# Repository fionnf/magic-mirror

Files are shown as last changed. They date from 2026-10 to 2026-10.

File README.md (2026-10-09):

# House Fortuna wall

A 192 × 192 pixel LED art wall for a living room: nine 64 × 64 HUB75 panels driven by a
Raspberry Pi 4, controlled from a phone web app. It shows slow generative art, GPU shaders and
video loops, responds (subtly) to the music in the room, and can also act as a camera mirror
with AI one-liners and a receipt printer.

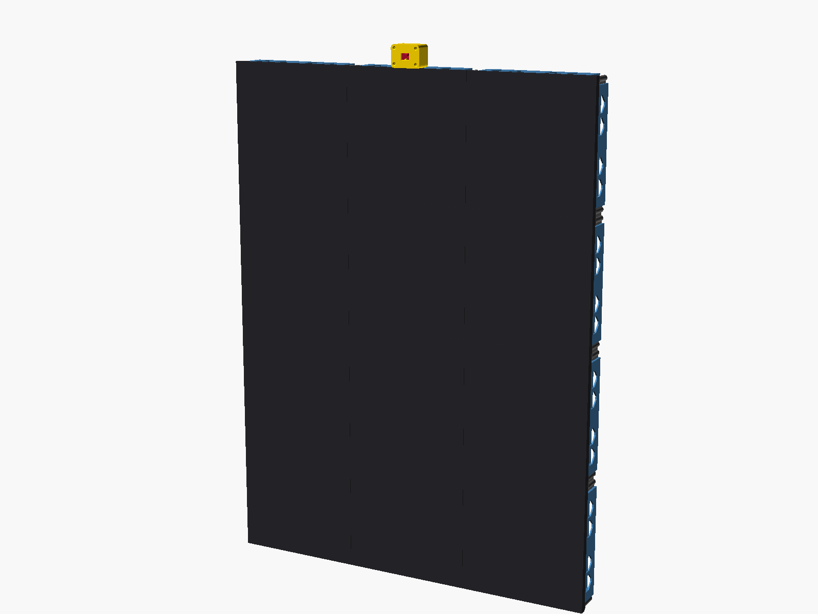
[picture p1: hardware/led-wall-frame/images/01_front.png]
front


## What it does

| Mode | What you see |
|---|---|
| **Art** (Artsy, Shaders, Shapes, Light Art, Lava & Coral) | Slow galleries that cross-fade; pace set in the app ("Art pace") |
| **Music** | Art that follows the room's sound. The party slider goes from "art just breathes" to dance floor; pieces, video loops and shaders are curated per level; a beat tracker, Shazam song names, an optional Claude designer |
| **Mirror** | Camera silhouette, countdown photo, a Claude one-liner, aura reading, pixel selfie, printed receipt; people recognition is opt-in |
| **Shows & live** | Welcome / Pride / story animations, VBZ-style tram board for Rennweg |
| **Extras** | Smart Life lights (living-room group), guest dedications via QR, a tour that rotates through everything |

## Hardware

| Part | Notes |
|---|---|
| Raspberry Pi 4 | Pi 5 is not supported by the panel library |
| Adafruit RGB Matrix HAT | `hardware_mapping = "regular"` (not `adafruit-hat`) |
| 9 × 64 × 64 HUB75 panels (P4, 256 mm) | 3 × 3, one chain, FM6126A driver, row serpentine from the bottom left (see `config.py`) |
| 5 V / 40 A PSU | Software current limiter at 28 A |
| Camera Module 3 | Mirror mode |
| Logitech C270 (its microphone) | Music mode's mic (any USB mic works) |
| 58 mm ESC/POS USB printer *(optional)* | Receipts |

The printable frame (3D models, OpenSCAD sources, print list) is in
[`hardware/led-wall-frame`](hardware/led-wall-frame/README.md).

## Quick start

**On a laptop (no hardware):**
```bash
python3 -m venv .venv && .venv/bin/pip install -r requirements-dev.txt
./panel_setup/sim.sh            # http://localhost:8080 - panels open in a window
```

**On a fresh Pi** (Raspberry Pi OS Lite 64-bit):
```bash
# laptop:
PI_USER=pi PI_HOST=<pi-ip> ./panel_setup/deploy.sh
scp .env pi@<pi-ip>:~/magic-mirror/.env
# pi:
cd ~/magic-mirror && ./panel_setup/bootstrap_pi.sh && sudo reboot
```
Then open `http://<pi-ip>/` on your phone. Details, tuning and troubleshooting:
[`panel_setup/README.md`](panel_setup/README.md).

## Configuration

`.env` (git-ignored; copy from `.env.example`):

| Variable | For |
|---|---|
| `ANTHROPIC_API_KEY` | All AI features (mirror lines, aura, booth prompts, wheel, music designer) - model `config.AI_MODEL` |
| `GOOGLE_DRIVE_FOLDER_ID`, `GOOGLE_DRIVE_RECEIPTS_FOLDER_ID` | Optional photo archive (`tools/auth_drive.py` once) |

Panel layout, timing, brightness and the power budget live in `config.py`.
App settings (party level, art pace, palette, people, lights…) are stored as JSON under
`panel_setup/` on the Pi and never deployed over.

## Layout

```
config.py, led_matrix.py      panel layout + driver (remapping, power limiter)
main.py, api.py               mirror mode (state machine) and its internal API
ai_client.py                  Claude calls (vision one-liner, aura, booth prompts, JSON helper)
camera.py, vision.py, smartcrop.py, faces.py, moods.py   camera, silhouette, crop, recognition
printer.py, photo_store.py, cloud_uploader.py           receipts and photo archive
lights.py                     Smart Life (Tuya) local control
display/                      everything drawn on the wall
  art.py shapes.py light_art.py artsy.py organic.py     generative galleries
  shaders.py (+ assets/shaders/*.frag)                  GPU shaders (EGL on the Pi)
  loops.py (+ assets/loops, tools/make_loops.py)        video loops
  music.py beat.py intensity.py vj_fx.py                music engine
  departures.py welcome.py pride_show.py …              live boards and shows
panel_setup/                  wall_control.py (app server + process runner), web/ (the app),
                              play.py (runs one mode), deploy/bootstrap/sim scripts, README
simulator/                    pygame panel window, webcam/button mocks
hardware/led-wall-frame/      the printable frame
```

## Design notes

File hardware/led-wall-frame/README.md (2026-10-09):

# Modular LED Wall Frame – 3 × 4 P4 64×64 panels (256 mm)

A fully printable, support-free mounting frame for twelve P4 64×64 HUB75 LED panels
(256 × 256 mm, e.g. `P4-2121-64X64-32S`) in a 3 × 4 grid. Overall size 768.6 × 1024.9 mm,
46 mm deep, so a Raspberry Pi 4/5 with HUB75 shield and a 5 V 40 A supply hide inside.
A small pod on the top edge holds a Raspberry Pi Camera Module 3 (or a Logitech C270).

Every part prints flat, with no supports, and fits a 250 × 220 mm bed (Prusa CORE One, Bambu X1/P1/H2, Prusa MK4…).
The compact Pi holder, camera pod, touch box and test pieces also fit 180 mm beds.

front

## What's in the box

| Folder | Contents |
|---|---|
| `3mf/` | Ready-to-slice plates, one object per part (open in PrusaSlicer, Bambu Studio, OrcaSlicer) |
| `stl/` | The same plates as STL |
| `source/` | Fully parametric OpenSCAD source (`led_wall_frame.scad`, `c270_webcam_box.scad`, `touch_box.scad`) |
| `images/` | Renders |

## Print list

| File | Qty | Notes |
|---|---|---|
| `00_fit_test_PRINT_FIRST` | 1 | Junction node + rail ends: check dovetail fit, M3 screw and wall keyhole |
| `00b_dovetail_gauge_c005_c010_c015` | 1 | Optional: 3 sockets at 0.05 / 0.10 / 0.15 mm clearance (1–3 dots) |
| `01_nodes_junction_x6` | 1 | |
| `02_nodes_edge_x10_corner_x4` | 1 | |
| `03_rails_vertical_x7` | 1 | |
| `04_rails_vertical_x1_horizontal_x6` | 1 | |
| `05_rails_horizontal_x3_outer_x6` | 1 | |
| `06_rails_outer_x7_top_mount_x1` | 1 | Includes the top-centre rail the camera pod screws to |
| `07_pi_tray_*` **or** `07_pi_holder_compact_*` | 1 | Pick one: full-width tray (stronger) or compact holder (fits 180 mm beds). `selftap` / `insert` (M2.5 heat-set) / `nut` (M2.5 bolt + nut). Pi 4 and Pi 5 share the hole pattern. |
| `08_psu_tray_A-200AF-5` | 1 | For a 190 × 84 × 30 mm 5 V 40 A supply (CZCL A-200AF-5) |
| `09_camera_module3_pod` **or** `10_c270_webcam_box` | 1 | Camera Module 3 (portrait, 15° down) or Logitech C270 (snap-on lid) |
| `11_touch_box_TTP223` / `11_touch_box_25mm_pad` | optional | 40 × 40 × 10 mm "roaming" capacitive touch button, 0.6 mm skin |
| `12_OPTIONAL_wall_ears_set` | optional | Only if you prefer ear brackets over the built-in keyholes |

Roughly 2 kg of filament for the full build.

## Print settings

- PETG (panels run warm – avoid PLA)
- 0.4 mm nozzle, 0.20 mm layers
- 5 perimeters, 40 % gyroid, 5 top / 5 bottom layers
- No supports, no brim, keep elephant-foot compensation on
- Print as laid out (panel side down). Touch box: front face down, 100 % infill.

## Hardware

| Item | Qty |
|---|---|
| M3 × 20 flat-head countersunk (DIN 7991 / ISO 10642) – panel screws | 84 (+2 optional) |
| 2 mm hex key with a long shaft (≥ 35 mm reach) | 1 |
| M3 × 12 pan/cheese head – camera pod or C270 box to the top rail | 2 |
| M3 × 12 countersunk – camera pod lid | 4 |
| M2 × 5 self-tapping – Camera Module 3 | 4 |
| M2.5 × 6 (+ 4 heat-set inserts for `insert`, or M2.5 × 10 + nuts for `nut`) – Pi | 4 |
| Zip ties ≥ 300 × 4.8 mm – around the PSU | 2 |
| Wall screws, pan head ≤ 8.2 mm, standing ~5 mm proud, + anchors (keyholes on a 256.3 mm grid) | 6 |
| Touch box: M2 × 8 countersunk self-tapping | 4 |
| Wall ears only: M3 × 50 countersunk at the 8 ear-node screws, 5 mm wall screws | 8 / 12 |

Electronics: 12 × P4 64×64 HUB75 panels, Raspberry Pi 5 (or 4) + active cooler, HUB75 driver shield,
Camera Module 3 + 500 mm camera cable (Pi 5: 22→15 pin) **or** Logitech C270, CZCL A-200AF-5 5 V 40 A supply,
HUB75 ribbons, panel power leads, 1.5–2.5 mm² 5 V wiring, mains cable, fuse + switch.

## Assembly

1. Lay the panels face down on a soft mat, all "up" arrows on the back pointing the same way.
2. Place the nodes on the panel corner inserts (8 mm from each edge).
3. Drop the rails in from above – the dovetails slide down over the node tenons. Horizontal rails: engraved arrow up.
4. Screw everything down with M3 × 20 (heads sit flush deep inside the posts).
5. Press the PSU tray and Pi tray into the rail windows: shift ~5 mm sideways, push one end's plugs in, bring the other end in, slide back to centre.
6. Fit the camera pod (or C270 box) on the top-centre rail; route the cable down through the rail window.
7. Hang the frame on six wall screws.

The two outer top rails have a mid screw hole at the top-centre of the outer panels – only use it if your panels have an insert there.

## Customising

All key values are at the top of `source/led_wall_frame.scad`:
`H` (frame depth), `screw_L` (panel screw length), `c` (dovetail clearance), `plug_cl` / `crush` (holder fit),
`pi_stack` (Pi + shield height), `psu_L` / `psu_Wd` (power supply size).

```
openscad -D 'part="plate_rails_A"' -o rails.stl source/led_wall_frame.scad
```

## Notes

- A single 200 W supply is short for 12 panels at full white (~240 W): cap the brightness (e.g. `--led-brightness`) or add a second supply.
- Mains: cover the AC terminals, strain-relieve the cable, fuse and switch outside the frame.
- Default Pi + shield stack: ≤ 32 mm above the Pi board.

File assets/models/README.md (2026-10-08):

# Models

`face_detection_yunet_2023mar.onnx` - YuNet face detector (~230 KB), used by `smartcrop.py` to keep
people in frame when photos are cut to portrait. Source: OpenCV Zoo
(https://github.com/opencv/opencv_zoo/tree/main/models/face_detection_yunet), MIT licence,
copyright (c) 2020 Shiqi Yu. Runs locally; nothing is sent anywhere. Needs OpenCV >= 4.5.4.

`face_recognition_sface_2021dec_int8.onnx` - SFace face recogniser (~9.9 MB, Apache-2.0, OpenCV Zoo
`face_recognition_sface`). Not committed: fetch with `./get_models.sh`. It turns a face into 128 numbers;
`faces.py` compares them. Only those numbers (never photos) are stored, and only for people who enrol.

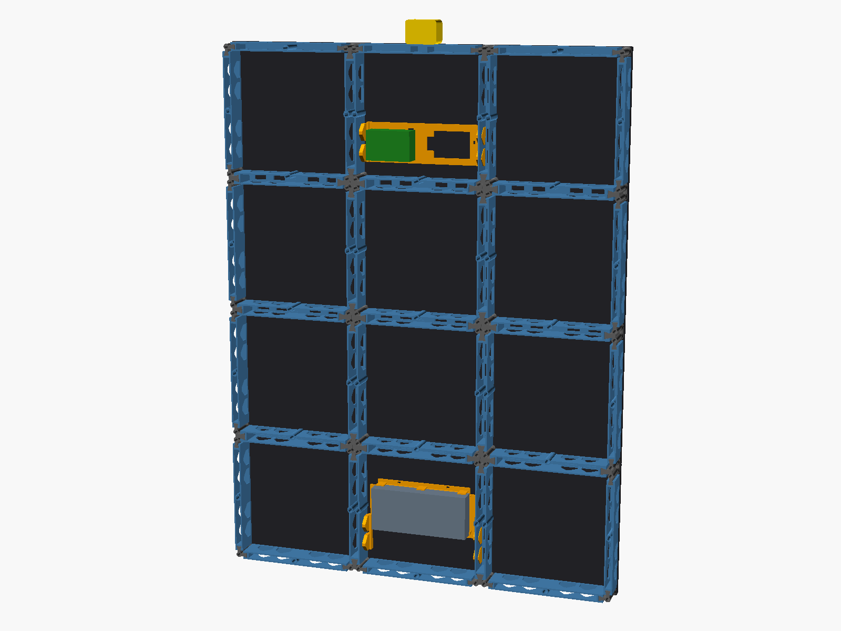
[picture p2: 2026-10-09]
hardware/led-wall-frame/images/02_rear.png

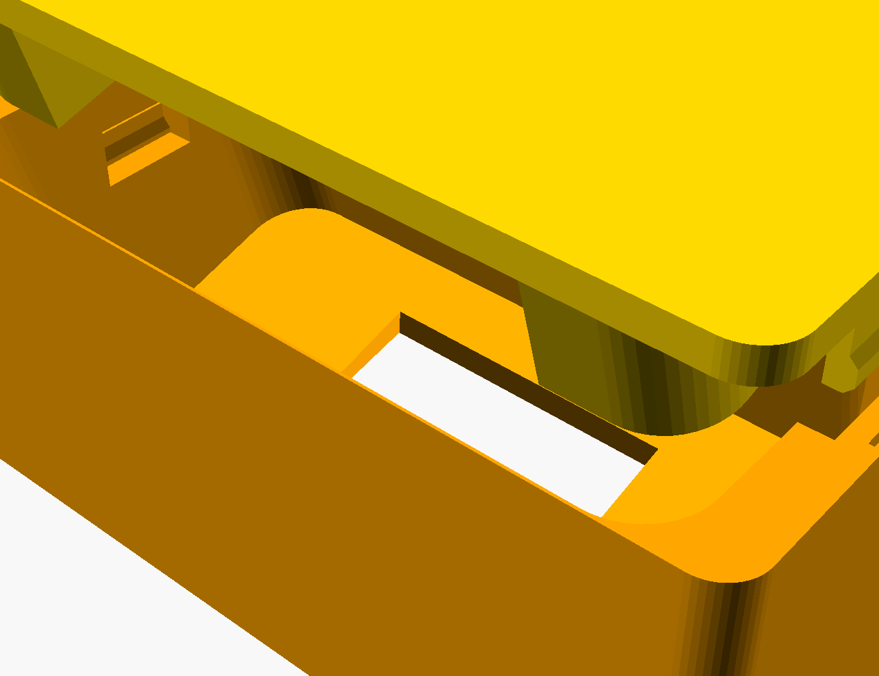
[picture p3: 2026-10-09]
hardware/led-wall-frame/images/12_c270_box_snap_lid.png

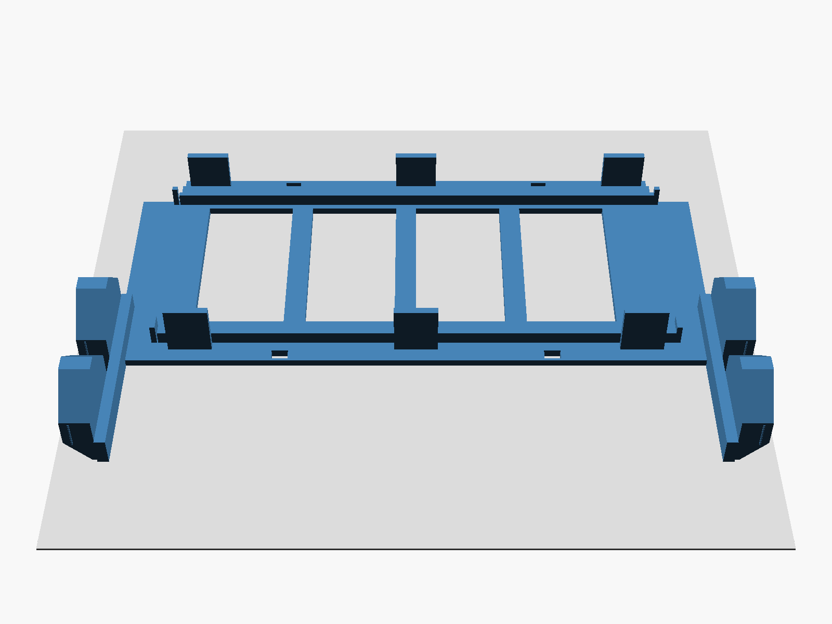
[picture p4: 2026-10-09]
hardware/led-wall-frame/images/10_plate_psu_tray.png

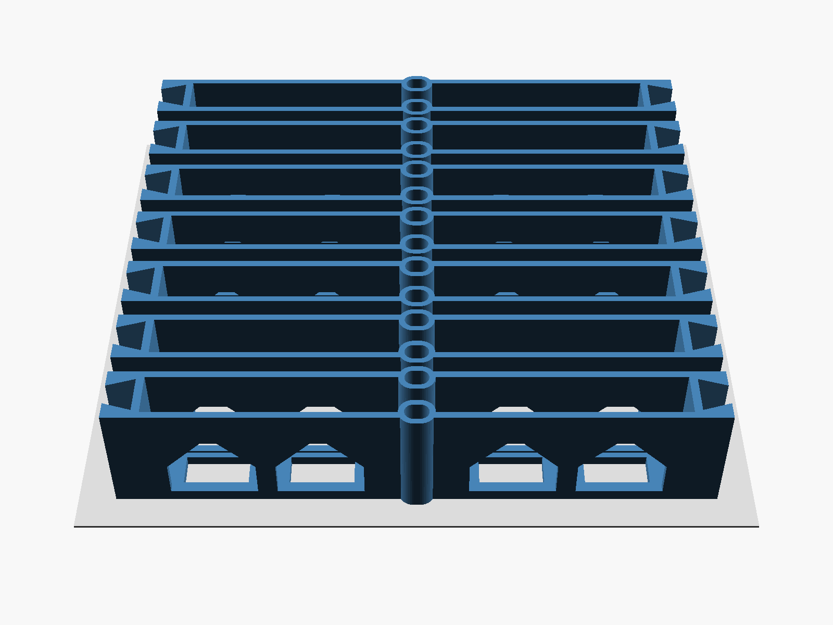
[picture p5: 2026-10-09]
hardware/led-wall-frame/images/09_plate_rails.png

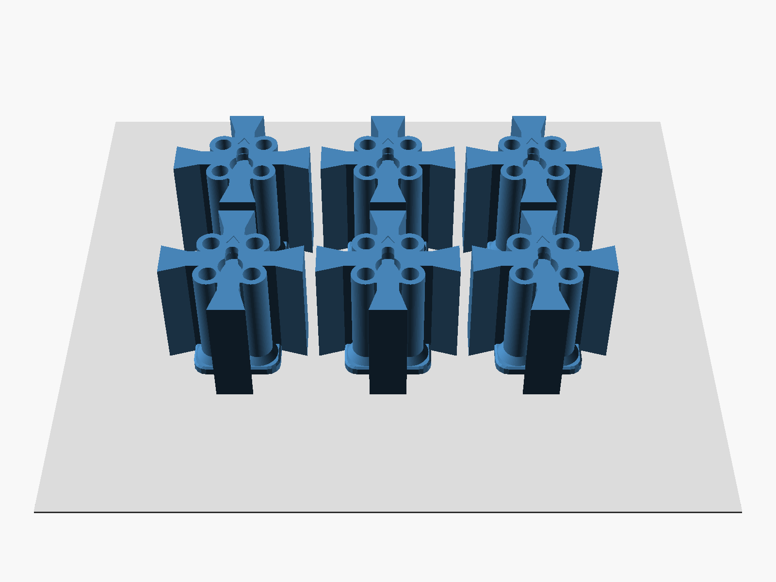
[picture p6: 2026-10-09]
hardware/led-wall-frame/images/08_plate_nodes.png

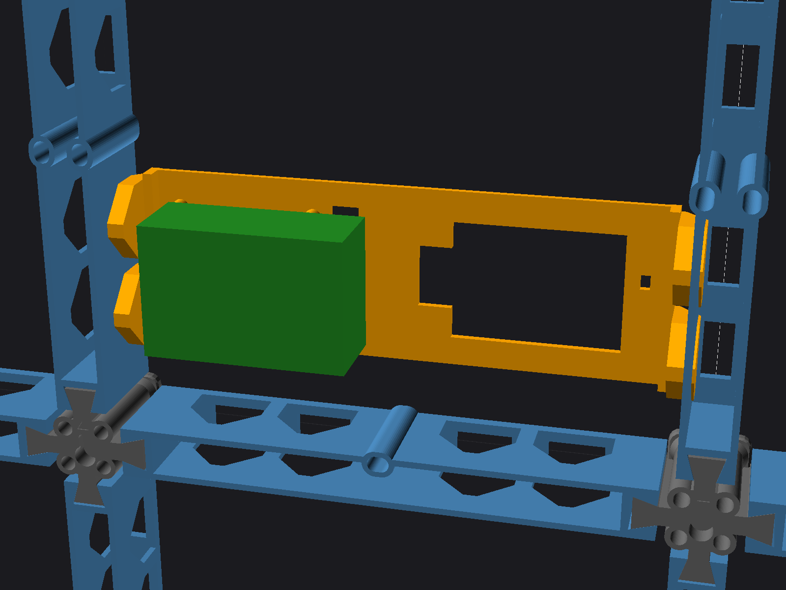
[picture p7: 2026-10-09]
hardware/led-wall-frame/images/04_pi_tray.png

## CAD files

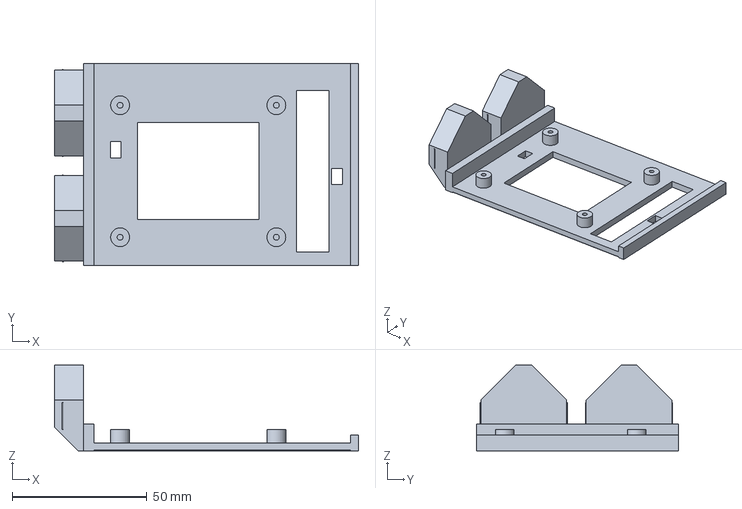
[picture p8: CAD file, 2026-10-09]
hardware/led-wall-frame/3mf/07_pi_holder_compact_selftap.3mf
112.9 x 75.0 x 31.9 mm

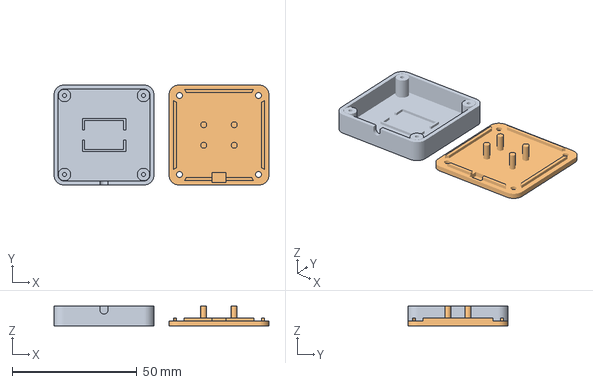
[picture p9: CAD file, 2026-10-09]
hardware/led-wall-frame/3mf/11_touch_box_TTP223.3mf
86.0 x 40.0 x 8.00 mm
touch box 1
touch box 2

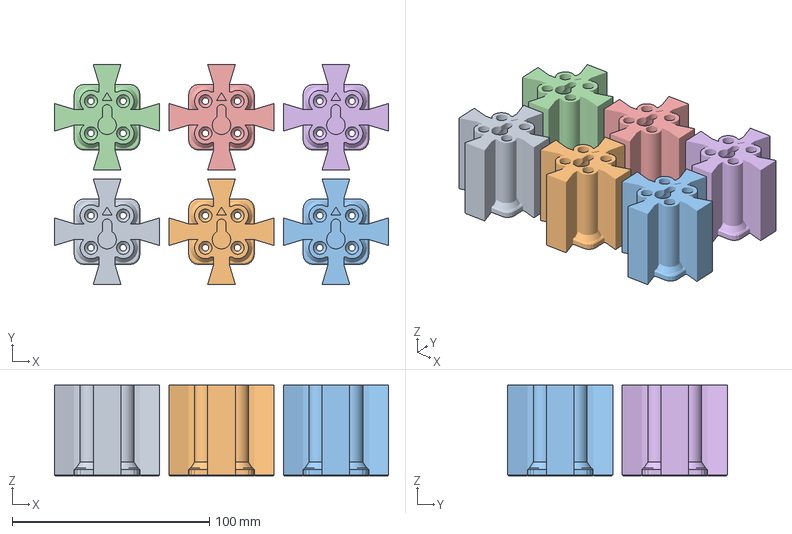
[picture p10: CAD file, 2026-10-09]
hardware/led-wall-frame/3mf/01_nodes_junction_x6.3mf
169.3 x 111.3 x 46.0 mm
junction node 1
junction node 2
junction node 3
junction node 4
junction node 5
junction node 6

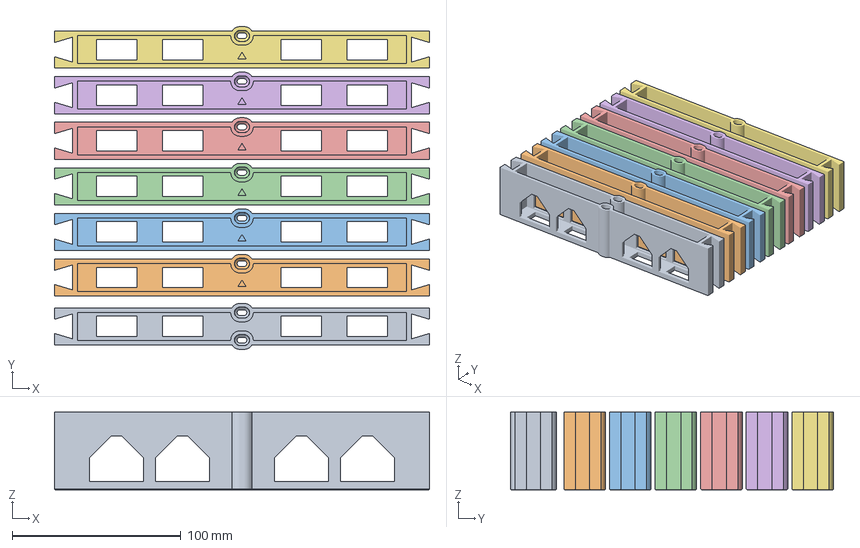
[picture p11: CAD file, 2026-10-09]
hardware/led-wall-frame/3mf/04_rails_vertical_x1_horizontal_x6.3mf
222.2 x 191.3 x 46.0 mm
rail 1
rail 2
rail 3
rail 4
rail 5
rail 6
rail 7

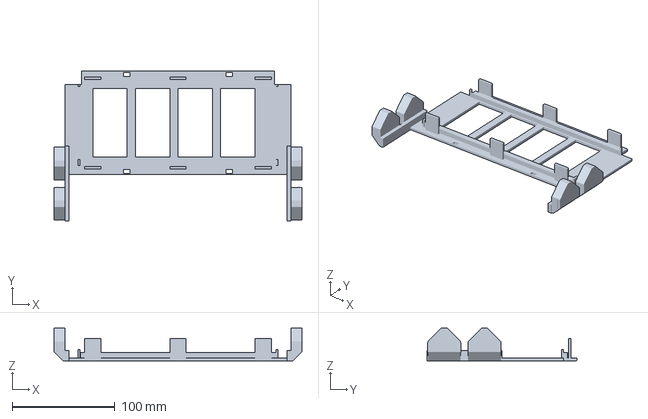
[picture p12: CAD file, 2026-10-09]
hardware/led-wall-frame/3mf/08_psu_tray_A-200AF-5.3mf
241.7 x 146.1 x 31.9 mm

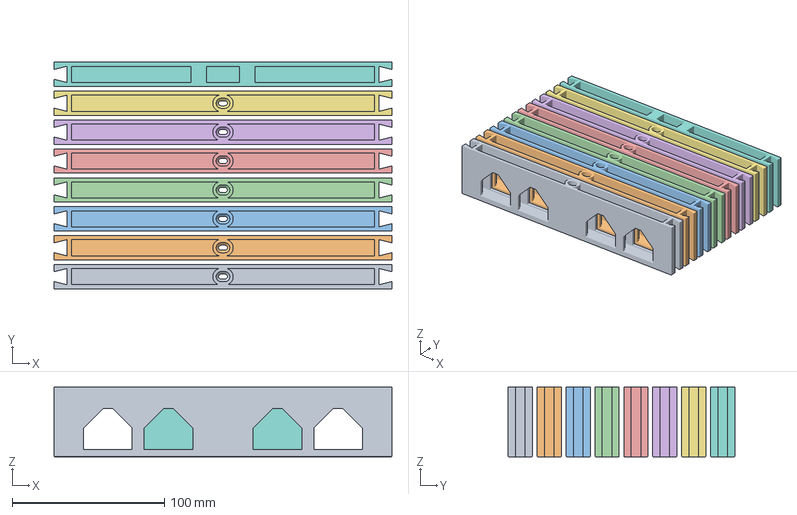
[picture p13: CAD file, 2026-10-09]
hardware/led-wall-frame/3mf/06_rails_outer_x7_top_mount_x1.3mf
222.2 x 149.0 x 46.0 mm
rail 1
rail 2
rail 3
rail 4
rail 5
rail 6
rail 7
rail 8

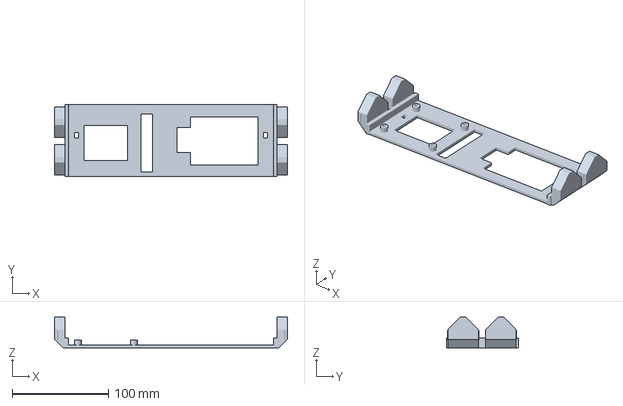
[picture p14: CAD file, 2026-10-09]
hardware/led-wall-frame/3mf/07_pi_tray_insert.3mf
241.7 x 75.0 x 31.9 mm

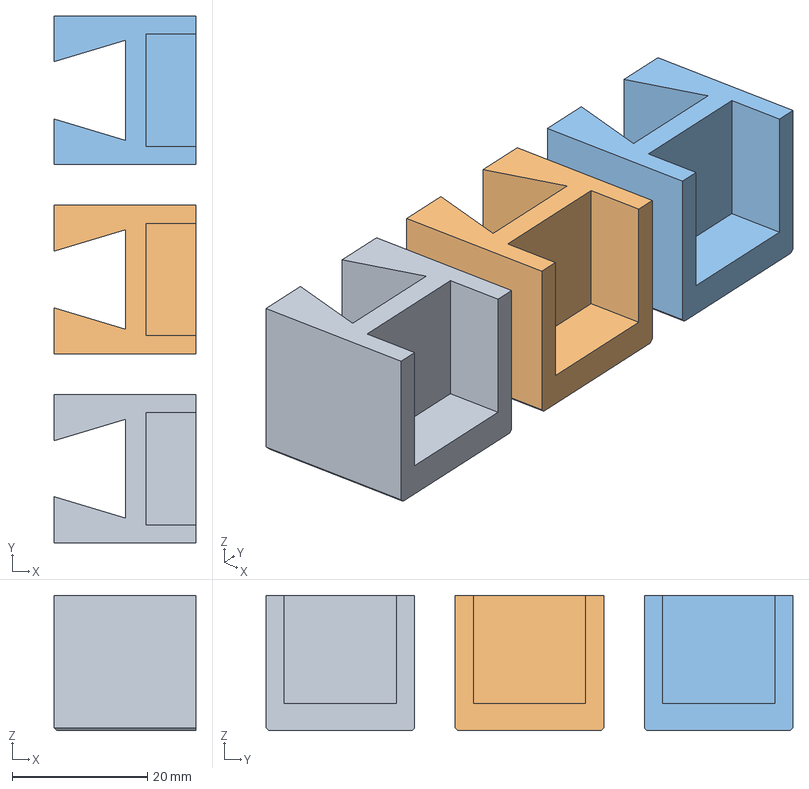
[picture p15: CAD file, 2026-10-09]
hardware/led-wall-frame/3mf/00b_dovetail_gauge_c005_c010_c015.3mf
21.0 x 78.0 x 20.0 mm
dovetail gauge 1
dovetail gauge 2
dovetail gauge 3

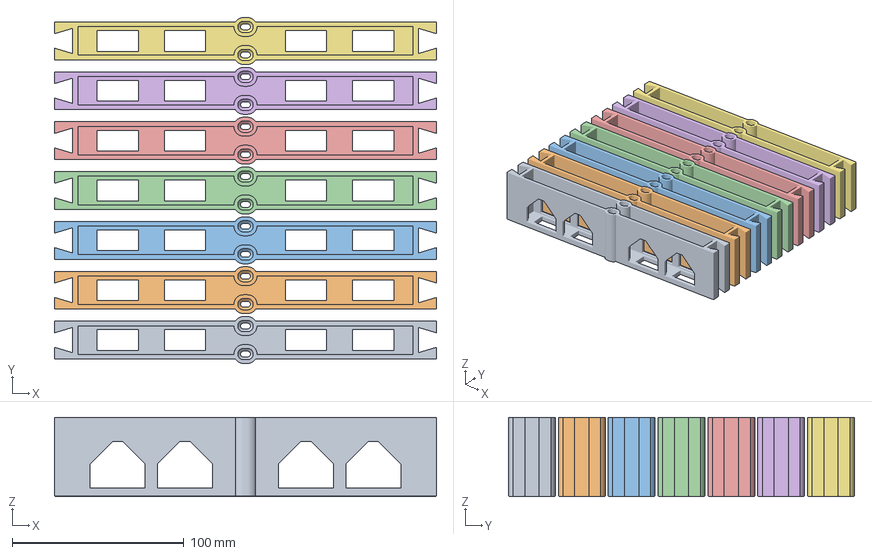
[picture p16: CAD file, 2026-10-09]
hardware/led-wall-frame/3mf/03_rails_vertical_x7.3mf
222.2 x 201.3 x 46.0 mm
vertical rail 1
vertical rail 2
vertical rail 3
vertical rail 4
vertical rail 5
vertical rail 6
vertical rail 7

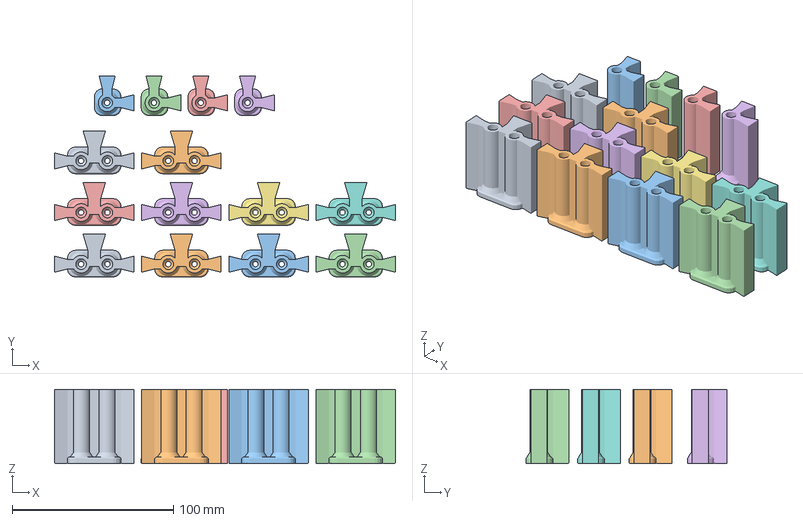
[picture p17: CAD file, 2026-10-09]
hardware/led-wall-frame/3mf/02_nodes_edge_x10_corner_x4.3mf
211.3 x 124.6 x 46.0 mm
edge/corner node 1
edge/corner node 2
edge/corner node 3
edge/corner node 4
edge/corner node 5
edge/corner node 6
edge/corner node 7
edge/corner node 8
edge/corner node 9
edge/corner node 10
edge/corner node 11
edge/corner node 12
edge/corner node 13
edge/corner node 14

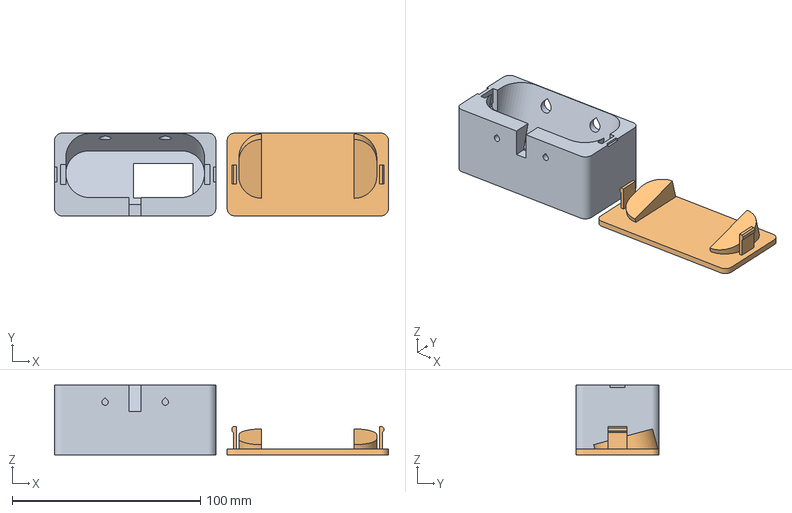
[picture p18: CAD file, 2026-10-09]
hardware/led-wall-frame/3mf/10_c270_webcam_box.3mf
177.6 x 44.0 x 37.0 mm
C270 box 1
C270 box 2

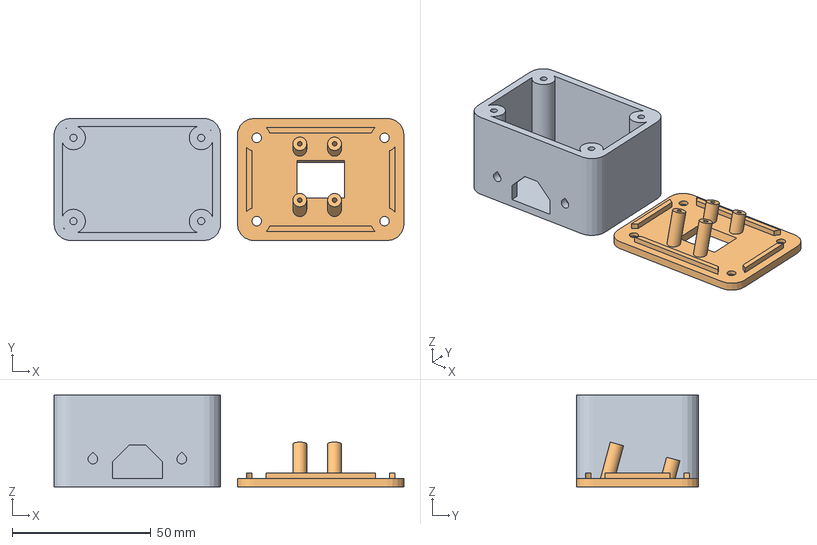
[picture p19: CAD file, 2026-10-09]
hardware/led-wall-frame/3mf/09_camera_module3_pod.3mf
126.0 x 44.0 x 33.0 mm
camera pod 1
camera pod 2

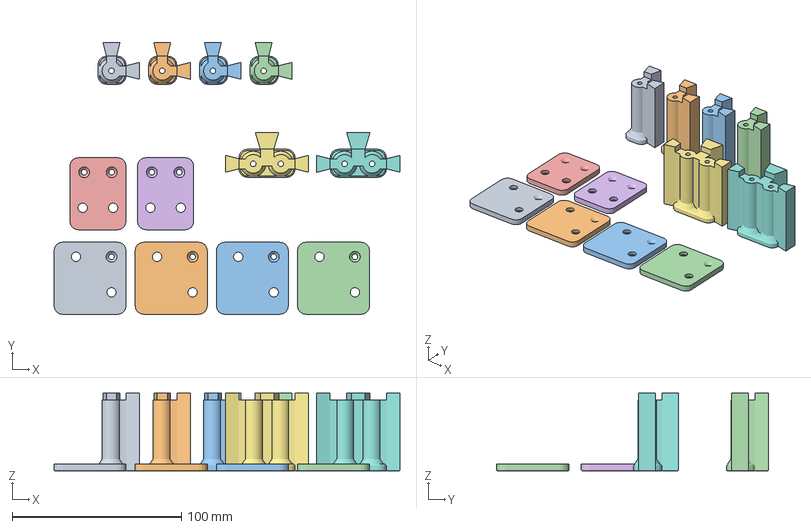
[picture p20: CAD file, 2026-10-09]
hardware/led-wall-frame/3mf/12_OPTIONAL_wall_ears_set.3mf
204.6 x 160.6 x 46.0 mm
wall ear part 1
wall ear part 2
wall ear part 3
wall ear part 4
wall ear part 5
wall ear part 6
wall ear part 7
wall ear part 8
wall ear part 9
wall ear part 10
wall ear part 11
wall ear part 12

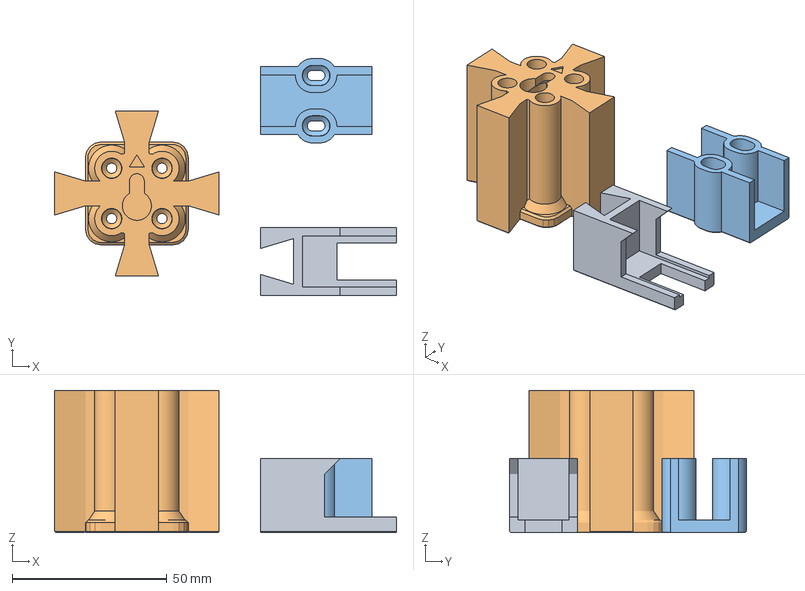
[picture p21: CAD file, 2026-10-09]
hardware/led-wall-frame/3mf/00_fit_test_PRINT_FIRST.3mf
110.6 x 76.6 x 46.0 mm
fit test 1
fit test 2
fit test 3

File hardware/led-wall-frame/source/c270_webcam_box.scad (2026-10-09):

// =====================================================================
// Logitech C270 webcam box for the P4 LED frame (top-centre, looks 15 deg down)
// Camera with its clip removed slides in from the back; the lid CLICKS shut
// (two snap tongues in the side walls) and its pads lock the camera. Two mounts:
//   mount = "clip" : peg into the window of the standard middle top rail + 1 zip tie
//   mount = "rail" : 2 x M3 into the pads of the full-frame top-mount rail
// part = "body" | "lid" | "plate" | "assembly"
// Print the body FRONT-DOWN (window on the bed), the lid outer-face-down. No supports.
// Default camera size = C270 body WITHOUT clip - measure yours and adjust cam_*.
// =====================================================================
part  = "plate";
mount = "clip";

cam_w = 73.0;   cam_h = 32.0;   cam_d = 24.0;   cam_r = 12;  // body (pill-shaped ends, from the photo); depth assumed - measure
lens_dx = 15;   lens_dy = 0;    // lens sits 15 mm off-centre (to the left seen from the front), from the photo
cl    = 0.4;    tilt = 15;      // pocket clearance, look-down angle
fov_h = 24.4 + 4;  fov_v = 14.3 + 4;   // half angles (55 deg dFOV, 16:9) + margin

// snap fit: tongues on the lid flex into slots in the thick side walls
snap_x0 = cam_w/2 + cl;        // slot opens onto the camera channel (tongue can flex inward)
tng_t = 1.6;  tng_w = 10;  tng_l = 12;  bump = 0.8;  snap_cl = 0.2;
tng_x = snap_x0 + 1.1;         // tongue inner face
wall = 2.6;  front_t = 2.4;  floor_t = 3;  roof_t = 2.5;  lid_t = 3;  press = 0.3;
W  = cam_w + 2*cl + 2*6;       // side walls thick enough for the lid screws
// camera front-face centre in box coords (x centred, y up from the frame top edge, z from the front face)
zf = front_t + cl + (cam_h/2)*sin(tilt) + 0.6;
yc = floor_t + cl + (cam_h/2)*cos(tilt);
Db = ceil(zf + (cam_h/2)*sin(tilt) + cam_d*cos(tilt) + cl + 1);    // body depth (lid on top)
Hb = ceil(yc + (cam_h/2)*cos(tilt) + cam_d*sin(tilt) + cl + roof_t);
D  = Db + lid_t;
echo(str("C270 box: ", W, " x ", Hb, " x ", D, " mm (w x h x depth)"));

// frame interface (matches p4_frame_v3: 46 mm frame, middle top rail)
z_front = -18;                 // frame z of the box front face (panel face is at -14)
peg_x = -36.3;   cab_x = 28;   // clip mount: peg window left of centre, cable window right of centre
pad_x = 16;      pad_z = 10;   // rail mount: screw pads of rail_top_mount

$fn = 48;
module rr(w, h, r) { offset(r) square([w-2*r, h-2*r], center=true); }
module cam_tf() { translate([lens_dx*0, yc, zf]) rotate([-tilt,0,0]) children(); }   // camera frame: front-face centre, +z = backwards
module cam_body(extra=0, back=0) {      // camera envelope (+ sweep out of the back for insertion)
  cam_tf() translate([0,0,-extra]) linear_extrude(cam_d + 2*extra + back) rr(cam_w+2*extra, cam_h+2*extra, cam_r+extra);
}
module teardrop2d(r) { hull() { circle(r=r); polygon([[-r*0.7071, r*0.7071],[r*0.7071, r*0.7071],[0, r*1.4142]]); } }
module lid_screws() { for (sx=[-1,1], yy=[6, Hb-6]) translate([sx*(W/2-3.2), yy]) children(); }

module body() {
  difference() {
    translate([0, Hb/2, 0]) linear_extrude(Db) rr(W, Hb, 4);
    cam_body(cl, 80);                                                  // pocket + back insertion sweep
    // lens window: flares at the field of view (plus margin) toward the outside
    cam_tf() translate([lens_dx, lens_dy, 0]) hull() {
      translate([0,0,1]) linear_extrude(0.01) square([30, 18], center=true);
      translate([0,0,-12]) linear_extrude(0.01) square([30 + 2*13*tan(fov_h), 18 + 2*13*tan(fov_v)], center=true);
    }
    for (sx=[-1,1]) mirror([sx<0 ? 1 : 0,0,0]) {
      // tongue slot from the back face, open to the camera channel
      translate([snap_x0-0.01, Hb/2-tng_w/2-snap_cl, Db-tng_l-0.5]) cube([tng_x+tng_t+snap_cl-snap_x0, tng_w+2*snap_cl, tng_l+1]);
      // catch: 45 deg on both sides -> clicks in, prints without support, opens with a firm pull
      translate([0, Hb/2-tng_w/2-snap_cl, 0]) rotate([90,0,0]) mirror([0,0,1]) linear_extrude(tng_w+2*snap_cl)
        translate([tng_x+tng_t, Db]) polygon([[0,-tng_l-0.2],[bump+snap_cl,-tng_l+bump+0.2-0.2+snap_cl],[bump+snap_cl,-tng_l+bump+1.6+snap_cl],[0,-tng_l+2*bump+1.6+2*snap_cl]]);
      // pry notch at the lid edge
      translate([W/2-1.2, Hb/2-4, Db-1.2]) cube([2, 8, 2]);
    }
    if (mount == "clip") {
      // cable channel down to the rail window, open to the lid (lay the cable in, plug stays outside the box)
      translate([cab_x-3.2, -1, Db-12]) cube([6.4, yc, 13]);
      translate([cab_x+6, -1, Db-9]) cube([4, floor_t+2, 5]);       // zip-tie slot
    } else {
      translate([-3.2, -1, Db-14]) cube([6.4, yc, 15]);              // cable channel into the rail's centre window
      for (sx=[-1,1]) {                                               // M3 into the rail pads + driver access through the roof
        translate([sx*pad_x, floor_t+1, pad_z - z_front]) rotate([90,0,0]) linear_extrude(floor_t+2) teardrop2d(1.7);
        translate([sx*pad_x, Hb+1, pad_z - z_front]) rotate([90,0,0]) linear_extrude(roof_t+2) teardrop2d(3.2);
      }
    }
  }
  if (mount == "clip")   // peg down into the rail window (frame z 6..16 at the root, 45 deg back face)
    translate([peg_x, 0, 0]) rotate([0,90,0]) rotate([0,0,90]) linear_extrude(6, center=true)
      polygon([[0.01, 6-z_front],[0.01, 16-z_front],[-6, 12-z_front],[-6, 6-z_front]]);
}

module lid() {
  difference() {
    union() {
      translate([0, Hb/2, 0]) linear_extrude(lid_t) rr(W, Hb, 4);
      // pusher pads at both ends of the camera (centre left free for the cable): fill the sweep behind the camera
      intersection() {
        translate([0,0,lid_t+Db]) mirror([0,0,1]) difference() {
          intersection() {
            cam_body(cl-0.2, 80);                                     // the insertion channel behind the camera
            cam_tf() translate([-100,-100,cam_d-press]) cube([200,200,200]);   // starts press mm INSIDE the camera back
          }
          translate([-cam_w/2+12, -50, -50]) cube([cam_w-24, 200, 200]);    // centre left free for the cable
        }
        translate([-W/2, 0, lid_t-0.01]) cube([W, Hb, Db]);
      }
    }
  }
  for (sx=[-1,1]) mirror([sx<0 ? 1 : 0,0,0]) translate([0, Hb/2-tng_w/2, 0]) rotate([90,0,0]) mirror([0,0,1]) linear_extrude(tng_w)
    polygon([[tng_x, lid_t-0.01],[tng_x+tng_t, lid_t-0.01],
             [tng_x+tng_t, lid_t+tng_l-2*bump-1.6],[tng_x+tng_t+bump, lid_t+tng_l-bump-1.6],
             [tng_x+tng_t+bump, lid_t+tng_l-bump],[tng_x+tng_t, lid_t+tng_l],[tng_x, lid_t+tng_l]]);
}

if (part == "body") body();
else if (part == "lid") lid();
else if (part == "plate") { body(); translate([W+6, 0, 0]) lid(); }
else {                      // assembly preview in box coords
  color("Orange") body();
  color("Gold") translate([0,0,D]) mirror([0,0,1]) lid();
  color("DimGray") cam_body(0, 0);
}

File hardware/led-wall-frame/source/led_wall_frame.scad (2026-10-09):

// =====================================================================
// P4 64x64 (256 x 256 mm) LED panels - 3 x 4 mounting frame - v3
// 20 mm deep, prints support-free on a Prusa CORE One (250 x 220 x 270).
//
// v2: rails also screw into the panels' mid-edge / bottom-centre inserts
//     (slotted holes), elephant-foot chamfers on every mating bottom edge,
//     45 deg self-supporting keyhole + windows, engraved UP arrows.
//
// part = "junction" "edge" "corner" "edge_ear" "corner_ear"
//        "bracket_edge" "bracket_corner"
//        "rail_v_inner" "rail_h_inner" "rail_outer"
//        "fit_test" "plate_nodes_A" "plate_nodes_B" "plate_ears"
//        "plate_rails_A" "plate_rails_B" "plate_rails_C" "plate_rails_D"
//        "rail_top_mount" "rail_h_pi" "box_A_body" "box_A_lid" "box_B_body" "box_B_lid"
//        "plate_rails_C2" "plate_rails_D_top" "plate_box_A" "plate_pi_box_B"
//        "assembly"   (preview; variant = "A" or "B", explode = 0..1)
//
// v3 adds a top-centre enclosure:
//   A: 20 mm frame + box on top holding Raspberry Pi 5 (+ shield) and Camera Module 3
//   B: 46 mm frame (-D H=46) with the Pi 5 on a platform inside the frame,
//      small camera-only box on top
// Camera looks out through the box front, tilted cam_tilt degrees down.
// Print everything with z = 0 on the bed (panel side down).
// =====================================================================
part    = "assembly";
explode = 0;
variant = "B";
panel_alpha = 0.35;   // render setting
show_mocks = true;

// ---------- panel / layout ----------
panel = 256;  gap = 0.3;  edge = 8;  cols = 3;  rows = 4;
P  = panel + gap;
hs = edge + gap/2;            // 8.15  insert offset from a seam centre line
a  = hs + 8.5;                // 16.65 node half size

// ---------- depth / plates ----------
H = 46;  plate_t = 4;  bracket_t = 4;
ef = 0.4;                     // elephant-foot chamfer on mating bottom edges
ch = 0.8;  r = 5;

// ---------- screws ----------
screw_d = 3.3;  head_d = 6.4;  head_dep = 2.5;
cs_d = 6.4;  cs_h = (cs_d - screw_d)/2;   // 90 deg countersink for M3 flat heads (DIN 7991 / ISO 10642)
screw_L = 20;  engage = 5;          // panel screws: M3 x screw_L
head_z  = screw_L - engage;         // screw head height above the rim face
cb_on   = H > head_z + 0.5;         // deep frames: counterbore so M3x25 still reaches
cb_d    = 6.6;
// ---- OPTIONAL adjustable nodes: every corner screw sits in a printed eccentric cam ----
// turn a cam (small flat screwdriver in its slot) to slide that panel corner up to +-cam_ecc
// in any direction, close the seam, then tighten. Off by default.
adj     = false;
cam_od  = 10;  cam_seat = 4;  cam_ecc = 0.6;  cam_cl = 0.1;
// tall cam: eccentric seat at the screw-head plane, tube rising to cam_top so the
// screwdriver slot is easy to reach from the back; the screw head sits deep inside it
cam_top = max(head_z + 6, H - 4);   // slot 4 mm below the back face
cam_h   = cam_top - (head_z - cam_seat);
tube_d  = adj ? 14 : (cb_on ? 11 : 9);  flare_d = tube_d + (adj ? 0.01 : 4);  flare_h = 3;
boss_d  = cb_on ? 11 : 10;  slot_play = 1.2;   // rail mid screws: slotted +-1.2 mm

// ---------- wall keyhole (junction nodes) ----------
slot_len = 8;  cw = 9.4;  sw = 4.8;  lip = 3;  chamber = 5.5;
taper_h = (cw - sw)/2;

// ---------- dovetails ----------
neck_w = 8;  head_w = 14;  tl_w = 10;     // interior seams
neck_n = 6;  head_n = 10;  tl_n = 8;      // perimeter
web_len = 10;  c = 0.1;  f = 0.3;  tenon_grow = 0;   // per side; the adjustable nodes are printed with 0.03          // c = dovetail clearance per side (was 0.2)
rail_L = P - gap/2 - 2*a - 2*f;           // 222.25
Ww = 22;  Wn = 16;  wall_t = 2.7;
deep = H >= 40;
old_windows = false;   // true = earlier 30 mm trapezoid windows (for checking add-ons)
win_len = (deep && !old_windows) ? 32 : 30;  mid_zone = 12;
win_side = 19;   // deep frames: vertical window sides up to this height (passes a 16-pin IDC plug)             // solid zone half-length around the mid screw

// ---------- brackets / engraving ----------
ear_out = 26;  wall_d = 5.5;  csk_d = 11;  engr = 0.6;

// =====================================================================
module rr(w, h, rad) { offset(rad) square([w-2*rad, h-2*rad], center=true); }
module rbox(x0, x1, y0, y1, rad) { translate([(x0+x1)/2,(y0+y1)/2]) rr(x1-x0, y1-y0, rad); }

module plate_body(x0, x1, y0, y1, rad) {
  hull() {
    linear_extrude(0.01) rbox(x0+ef, x1-ef, y0+ef, y1-ef, rad-ef);
    translate([0,0,ef]) linear_extrude(plate_t-ch-ef) rbox(x0, x1, y0, y1, rad);
    translate([0,0,plate_t-ch]) linear_extrude(ch) rbox(x0+ch, x1-ch, y0+ch, y1-ch, rad-ch);
  }
}
module post(x, y, ph) {
  translate([x, y, plate_t-0.01]) {
    cylinder(d1=flare_d, d2=tube_d, h=flare_h, $fn=64);
    cylinder(d=tube_d, h=ph-plate_t+0.01, $fn=64);
  }
}
module bore(x, y, ph) {
  if (adj && ph == H) {
    translate([x, y, -0.01]) cylinder(d=screw_d+2*cam_ecc+0.3, h=ph+0.02, $fn=48);
    translate([x, y, head_z-cam_seat]) cylinder(d=cam_od+2*cam_cl, h=H, $fn=64);   // cam bore, open to the back (cam drops in)
  } else {
  translate([x, y, -0.01]) cylinder(d=screw_d, h=ph+0.02, $fn=48);
  if (ph == H) {
    zc = cb_on ? head_z : H;                          // head sits flush here
    translate([x, y, zc-cs_h]) cylinder(d1=screw_d, d2=cs_d, h=cs_h+0.01, $fn=48);
    if (cb_on) translate([x, y, head_z]) cylinder(d=cb_d, h=H, $fn=48);
  }
  }
}
module adj_cam() {   // print standing, slot end up; the arrow on top points AWAY from the offset
  bore = cs_d + 0.2;                                   // bore above the seat, on the screw axis (passes the head / hex key)
  difference() {
    cylinder(d=cam_od, h=cam_h, $fn=64);
    translate([cam_ecc,0,-0.01]) cylinder(d=screw_d, h=cam_seat+0.02, $fn=40);         // eccentric screw hole
    translate([cam_ecc,0,cam_seat-cs_h]) cylinder(d1=screw_d, d2=cs_d, h=cs_h+0.01, $fn=40);   // countersunk seat
    translate([cam_ecc,0,cam_seat]) cylinder(d=bore, h=cam_h, $fn=48);                 // head / hex-key access
    translate([-cam_od/2-1, -0.8, cam_h-2]) cube([cam_od+2, 1.6, 2.1]);                 // screwdriver slot across the top
    translate([-cam_od/2+0.4, 2.0, cam_h-0.5]) linear_extrude(0.6) polygon([[0,-0.8],[0,0.8],[-1.0,0]]);
  }
}
module up_arrow(x, y, z) {    // engraved triangle pointing +y
  translate([x, y, z-engr]) linear_extrude(engr+0.01) polygon([[-2.5,-1.5],[2.5,-1.5],[0,2.5]]);
}

// ---------- dovetail tenon (on nodes) ----------
module trap2d(nw, hw, tl) polygon([[0,-nw/2],[tl,-hw/2],[tl,hw/2],[0,nw/2]]);
module tenon(px, py, ang, nw, hw, tl, ph) {
  translate([px, py, 0]) rotate([0,0,ang]) {
    translate([-web_len, -nw/2, 0]) cube([web_len+0.01, nw, ph]);
    hull() {   // tenon_grow > 0 makes the joint tighter without reprinting rails
      linear_extrude(0.01) offset(delta=-ef+tenon_grow) trap2d(nw, hw, tl);
      translate([0,0,ef]) linear_extrude(H-ef) offset(delta=tenon_grow) trap2d(nw, hw, tl);
    }
  }
}
module tenon_w(px,py,ang,ph) tenon(px,py,ang,neck_w,head_w,tl_w,ph);
module tenon_n(px,py,ang,ph) tenon(px,py,ang,neck_n,head_n,tl_n,ph);

// ---------- dovetail socket (in rails) ----------
function sd_(tl) = tl - f + 0.9;
function w0_(nw,hw,tl)  = nw + (hw-nw)*f/tl + 2*c;
function wsd_(nw,hw,tl) = nw + (hw-nw)*(sd_(tl)+f)/tl + 2*c;
module strap2d(nw, hw, tl) {
  sd = sd_(tl); w0 = w0_(nw,hw,tl); wsd = wsd_(nw,hw,tl);
  polygon([[0,-w0/2],[sd,-wsd/2],[sd,wsd/2],[0,w0/2]]);
}
module socket_cut(nw, hw, tl) {
  w0 = w0_(nw,hw,tl);
  translate([0,0,-1]) linear_extrude(H+2) {
    strap2d(nw, hw, tl);
    translate([-1,-w0/2]) square([1.01, w0]);
  }
  hull() {   // bottom chamfer so first-layer squish can't bind the joint
    translate([0,0,-0.01]) linear_extrude(0.01) offset(delta=ef) strap2d(nw, hw, tl);
    translate([0,0,ef]) linear_extrude(0.01) strap2d(nw, hw, tl);
  }
}

// ---------- keyhole ----------
module slot_stadium() { hull() { translate([0,-slot_len/2]) circle(d=sw,$fn=48); translate([0,slot_len/2]) circle(d=sw,$fn=48); } }
module chamber_shape() { hull() { translate([0,-slot_len/2]) circle(d=cw,$fn=64); translate([0,slot_len/2]) circle(d=cw,$fn=64); } }
module keyhole_cut() {
  bottom = H - lip - chamber;
  translate([0,-slot_len/2,bottom]) cylinder(d=cw, h=chamber+lip+0.01, $fn=64);
  translate([0,0,bottom]) linear_extrude(chamber-taper_h) chamber_shape();
  hull() {
    translate([0,0,H-lip-taper_h]) linear_extrude(0.01) chamber_shape();
    translate([0,0,H-lip]) linear_extrude(0.01) slot_stadium();
  }
  translate([0,0,H-lip-0.01]) linear_extrude(lip+0.02) slot_stadium();
}
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

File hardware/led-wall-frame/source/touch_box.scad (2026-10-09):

// =====================================================================
// "Roaming" touch box - 40 x 40 x 10 mm, capacitive touch sensor behind
// an ultra-thin printed front skin. Screws shut (4 x M2 x 8), single cable
// exit clamped between body and lid (built-in strain relief).
//   part = "body" | "lid" | "plate" | "assembly"
// Print the body FRONT-DOWN (skin on the bed = smooth face), lid outer-face-down.
// No supports. Print the front skin solid (it is only skin_t thick).
// =====================================================================
part = "plate";
explode = 0;                      // assembly preview only

W = 40;  D = 10;  r = 4;          // outer size, total depth, corner radius
wall   = 1.6;
skin_t = 0.6;                     // ultra-thin front: 3 layers at 0.2 mm (0.4 = 2 layers, more sensitive, more fragile)
lid_t  = 2;
lip_h  = 1.2;  lip_cl = 0.2;

// touch sensor board (default: common TTP223 module 15 x 11 x 1.6, pad side against the skin)
sensor = "TTP223";                // "TTP223" or "PAD25" (25 x 25 mm large-pad module)
sb = (sensor == "PAD25") ? [25.4, 25.4] : [15.2, 11.2];
sb_t = 1.6;  sb_cl = 0.3;  rib_h = 1.0;  rib_t = 0.8;
press = 0.2;                      // pusher interference, keeps the pad pressed on the skin

// screws
scr_in = 4.2;                     // corner screw inset from the outer edge
pilot  = 1.6;  boss_d = 5;  scr_d = 2.3;  csk_d = 4.3;

// cable exit (e.g. 3-core 3.5 mm cable for VCC / GND / OUT), clamped 0.3 undersize
cable_d = 3.5;  clamp = 0.3;

$fn = 48;
inner_D = D - lid_t;              // body height (front skin + walls)

module rr(w, h, rad) { offset(rad) square([w-2*rad, h-2*rad], center=true); }
module corners() { for (sx=[-1,1], sy=[-1,1]) translate([sx*(W/2-scr_in), sy*(W/2-scr_in)]) children(); }

module body() {
  difference() {
    union() {
      difference() {
        linear_extrude(inner_D) rr(W, W, r);
        translate([0,0,skin_t]) linear_extrude(inner_D) rr(W-2*wall, W-2*wall, r-wall);
      }
      corners() cylinder(d=boss_d, h=inner_D);                       // screw bosses
      // sensor locating ribs on the back of the skin
      translate([0,0,skin_t-0.01]) linear_extrude(rib_h) difference() {
        square([sb[0]+2*sb_cl+2*rib_t, sb[1]+2*sb_cl+2*rib_t], center=true);
        square([sb[0]+2*sb_cl, sb[1]+2*sb_cl], center=true);
        for (sx=[-1,1]) translate([sx*(sb[0]/2+sb_cl+rib_t/2), 0]) square([rib_t+0.2, 4], center=true);   // finger gaps to lift the board
      }
    }
    corners() translate([0,0,skin_t+0.6]) cylinder(d=pilot, h=inner_D);
    // cable exit: U-slot from the top edge; the flat lid face squeezes the cable (strain relief)
    hull() for (zz=[inner_D-(cable_d-clamp)/2, inner_D+2])
      translate([0, -W/2-1, zz]) rotate([-90,0,0]) cylinder(d=cable_d-clamp, h=wall+2);
  }
}

module lid() {
  difference() {
    union() {
      linear_extrude(lid_t) rr(W, W, r);
      // locating lip that drops inside the walls
      translate([0,0,lid_t-0.01]) linear_extrude(lip_h) difference() {
        rr(W-2*wall-2*lip_cl, W-2*wall-2*lip_cl, r-wall-lip_cl);
        rr(W-2*wall-2*lip_cl-2.4, W-2*wall-2*lip_cl-2.4, 1);
        corners() circle(d=boss_d+1);
      }
      // 4 slightly flexible pushers on the sensor board corners
      for (sx=[-1,1], sy=[-1,1])
        translate([sx*(sb[0]/2-1.5), sy*(sb[1]/2-1.5), lid_t-0.01])
          cylinder(d=2.4, h=(inner_D - skin_t - sb_t) + press + 0.01);
    }
    corners() {
      translate([0,0,-0.01]) cylinder(d=scr_d, h=lid_t+lip_h+1);
      translate([0,0,-0.01]) cylinder(d1=csk_d, d2=scr_d, h=(csk_d-scr_d)/2+0.01);   // countersink (prints as 45 deg)
    }
    // clearance in the lip where the cable comes in
    translate([0, -W/2+wall+lip_cl+1.2, lid_t]) cube([cable_d+2, 4, 2*lip_h+1], center=true);
  }
}

module mock_sensor() { color("Green") translate([-sb[0]/2, -sb[1]/2, skin_t]) cube([sb[0], sb[1], sb_t]); }
module mock_cable()  { color("Black") translate([0, -W/2-15, inner_D-cable_d/2+clamp/2]) rotate([-90,0,0]) cylinder(d=cable_d, h=15+wall+3); }

if (part == "body") body();
else if (part == "lid") lid();
else if (part == "plate") { body(); translate([W+6, 0, 0]) lid(); }
else {   // assembly: front at z = 0, lid flipped on top
  color("Orange") body();
  color("Gold") translate([0,0,D+explode]) mirror([0,0,1]) lid();
  mock_sensor(); mock_cable();
}

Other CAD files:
hardware/led-wall-frame/3mf/07_pi_tray_selftap.3mf
hardware/led-wall-frame/3mf/11_touch_box_25mm_pad.3mf
hardware/led-wall-frame/3mf/07_pi_holder_compact_insert.3mf
hardware/led-wall-frame/3mf/05_rails_horizontal_x3_outer_x6.3mf
hardware/led-wall-frame/3mf/07_pi_holder_compact_nut.3mf
hardware/led-wall-frame/3mf/07_pi_tray_nut.3mf
hardware/led-wall-frame/stl/00_fit_test_PRINT_FIRST.stl
hardware/led-wall-frame/stl/00b_dovetail_gauge_c005_c010_c015.stl
hardware/led-wall-frame/stl/01_nodes_junction_x6.stl
hardware/led-wall-frame/stl/02_nodes_edge_x10_corner_x4.stl
hardware/led-wall-frame/stl/03_rails_vertical_x7.stl
hardware/led-wall-frame/stl/04_rails_vertical_x1_horizontal_x6.stl
hardware/led-wall-frame/stl/05_rails_horizontal_x3_outer_x6.stl
hardware/led-wall-frame/stl/06_rails_outer_x7_top_mount_x1.stl
hardware/led-wall-frame/stl/07_pi_holder_compact_insert.stl
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

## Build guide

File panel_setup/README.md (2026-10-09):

# Running the wall (9 × 64×64 HUB75, 3 × 3, 192 × 192 px)

How to install, deploy, run, tune and troubleshoot the wall. Everything reads `../config.py`
(panel layout, chain order, timing, power). For an overview see the top-level README.

## 0. On a laptop: the simulator
```bash
./panel_setup/sim.sh        # http://localhost:8080, panels open in a window
```
Same app and modes as on the Pi; music listens to the Mac microphone (`MIC="..."` to choose),
mirror mode uses the Mac webcam. GPU shaders need `pip install moderngl`.

## 1. Install on the Pi (once)
See *New Pi from scratch* below: deploy, then `./panel_setup/bootstrap_pi.sh` and a reboot.
It installs the system packages, compiles the panel library, installs the Python packages,
turns off the onboard audio (it conflicts with the panels), installs the `wall-control`
service (the app on port 80) and runs a health check.

## 2. Send code to the Pi (from your laptop)
```bash
PI_USER=pi PI_HOST=192.168.1.129 ./panel_setup/deploy.sh
```
It rsyncs the project to `~/magic-mirror` (skips `.env`, tokens, photos, git, and the Pi's own
settings/state files). Then `sudo systemctl restart wall-control` on the Pi.

## 3. Run on the Pi
```bash
ssh pi@192.168.1.129
cd ~/magic-mirror
sudo systemctl stop wall-control    # the app drives the panels; stop it for the bring-up tools
./panel_setup/run.sh walk         # START HERE: one panel at a time
```
Ctrl-C quits (display is cleared).

| Command | Purpose |
|---|---|
| `run.sh walk` | One panel lit at a time in chain order, 3 s each, with corner dots + index. `--panel 5` holds one, `--walk-sec 6` slows it |
| `run.sh numbers` | Each panel shows its chain index + up arrow. Verify order/orientation |
| `run.sh gradient` | Colour channels, dead pixels |
| `run.sh bar --show-refresh` | Moving bar: flicker / tearing / refresh rate |
| `run.sh text` / `anim` | Project text renderer and animations |
| `run.sh white` | Worst-case power draw — **watch the PSU** |
| `run.sh` | Cycle everything |
| `run.sh tune` | Steps through light→heavy timing presets (12 s each); pick the lightest that looks clean |
| `run.sh monitor` | Pi health only (run in a 2nd SSH window) |
| `run.sh --single` | One panel only (`--mapping`, `--multiplexing`) |

Tuning flags (override `config.py` for one run): `--brightness --pwm-bits
--lsb-ns --slowdown --refresh-limit --multiplexing --row-address --mapping`.

## Keeping the load light
The refresh thread always uses one core (see above); what we control is how hard
it works and how much Python adds. Already done in `led_matrix.py`:
- panel remap is a precomputed reshape/index (~0.1 ms/frame — never the bottleneck);
- power estimate uses a 1-in-16 pixel subsample;
- **unchanged frames are not re-uploaded** — static text/held frames cost ~0.

Tuning (`./panel_setup/run.sh tune`): the defaults are `pwm_bits=7`, slowdown 3, `panel_type FM6126A`, mapping `regular`.
Colour depth per channel is 2^bits levels (7 → 128, 8 → 256, 6 → 64). The
library already applies luminance correction, so 7 bits still looks smooth in
normal content; `pwm_dither_bits=1` recovers smooth fades for a small refresh
cost. `gpio_slowdown` 3 is confirmed on these panels; lower values are untested here. Use the
lightest preset that shows no flicker, banding or noise on the bar test.

## Pi health monitoring
Every test prints a `[PI]` line every 2 s and logs to `panel_setup/monitor.csv`:
```
[PI] cpu  62% (worst core 98%) | 58°C 1800MHz | mem 14% |  29.8 fps draw 11.2ms (max 25) | ~5.0A | ok
```
- **worst core ~100%**: the matrix refresh thread is saturating a core — expected;
  use `isolcpus=3` so it has one to itself.
- **fps below target / draw ms high**: Python remap+SetImage is the bottleneck.
- **temp ≥ 75°C** warns once; ≥ 80°C means throttling is close — add a heatsink/fan.
- **UNDERVOLTAGE / THROTTLED** flags come from `vcgencmd get_throttled`. Undervoltage
  = the Pi's 5 V is sagging; check the Pi's own supply and panel power wiring.
- Copy the CSV back with `scp <user>@<host>:magic-mirror/panel_setup/monitor.csv .`
 .

## 4. Fix what you see
- **Indices not 0,1,2… along the cable** → edit `PANEL_CHAIN_ORDER` in `config.py`
  (list of `(col, row)` per chain position, starting at the HAT cable).
- **A panel upside down** → `PANEL_ROTATE = {chain_index: 180}`.
- **Scrambled/striped image** → `--multiplexing 1` (or 2, 4); try `--row-address 3`.
- **Flicker / low refresh** → lower `--pwm-bits` (7→6), `--lsb-ns` (130→100),
  `--slowdown` (4→2); add `isolcpus=3` to `/boot/firmware/cmdline.txt`;
  disable onboard audio (done by `bootstrap_pi.sh`: it also blacklists `snd_bcm2835`).

## Power (40 A @ 5 V PSU)
12 panels at full white ≈ 48 A. Protections:
- `MATRIX_BRIGHTNESS = 40` (full white ≈ 19 A)
- `MATRIX_MAX_AMPS = 28`: the driver estimates current per frame and dims it
  to stay under budget. `MATRIX_AMPS_PER_PANEL = 4.0` is a guess — measure.
- Give each panel (or pair) its own power lead to the PSU. Share GND with the Pi only.

## New Pi from scratch
1. Raspberry Pi Imager: Raspberry Pi OS Lite (64-bit), user `pi`, hostname, your **home** Wi-Fi,
   SSH on with your public key (`~/.ssh/id_rsa.pub`).
2. Boot with the camera ribbon already attached (the CSI port is only probed at power-on).
3. Join a network (see below), then from the laptop: `PI_HOST=<ip> ./panel_setup/deploy.sh`
4. On the Pi: `cd ~/magic-mirror && ./panel_setup/bootstrap_pi.sh && sudo reboot`
5. Copy the secrets over: `.env` (and `token.json` / `oauth_client.json` if Drive uploads are used).

Joining eduroam on a keyboard-only Pi (NetworkManager). `--ask` prompts for the password so it
never lands in the shell history; check the exact identity / CA settings with your institution's
eduroam page (or https://cat.eduroam.org):
```
sudo nmcli --ask connection add type wifi con-name eduroam ifname wlan0 ssid eduroam \
  wifi-sec.key-mgmt wpa-eap 802-1x.eap peap 802-1x.phase2-auth mschapv2 \
  802-1x.identity "USERNAME@your.institution" 802-1x.system-ca-certs yes
sudo nmcli connection up eduroam
```
A web-login ("captive portal") network cannot be completed on a headless Pi: use eduroam,
Ethernet, or a phone hotspot instead.

## Portrait photos that keep people in frame
Every photo (the picture the AI comments on, the receipt, the photobooth shots) is cut to
portrait **around the people**: a small local face detector (`smartcrop.py`, model in
`assets/models/`) places the crop over everyone's face; if no face is found it uses where the
scene changed against the empty room, then the centre. The website's Mirror card has a switch
("Follow people when cropping photos to portrait") and shows the last photo with the AI's line.
The live silhouette on the wall keeps its cheap centred crop.

## Smart Life lights (Tuya, local control)
The website's **Lights** card switches your Smart Life lights/plugs off (and on) over the home
network with `tinytuya` - fast, no cloud at runtime, works if the internet is down - plus an
optional nightly "lights off at HH:MM". Google Home is not needed. One-time setup, **at home**
(the laptop must be on the same Wi-Fi as the lights); each light's *local key* comes from Tuya's
developer cloud:
1. Create a free account at https://iot.tuya.com -> Cloud -> Development -> **Create Cloud Project**
   (industry "Smart Home", data centre **Central Europe** for Switzerland). Note its **Access ID**
   and **Access Secret**. Under the project's *Service API*, make sure **IoT Core** and
   **Authorization** are subscribed.
2. In the project, *Devices* -> **Link Tuya App Account** -> *Add App Account*, and scan the QR code
   with the **Smart Life** app (Me -> the scan icon). Your lights now appear under the project.
3. On the laptop, in the project folder:
   `pip install tinytuya && python -m tinytuya wizard`
   Enter the Access ID, the Access Secret, any one device ID from the project's device list and the
   region (`eu` for Central Europe); say yes to scanning the network for IP addresses. It writes
   `devices.json` (names, local keys, IPs) - and `tinytuya.json` (your API secret).
4. `./panel_setup/deploy.sh` copies `devices.json` to the Pi (not `tinytuya.json`), then on the Pi
   `sudo pip3 install --break-system-packages tinytuya` (the bootstrap script does this) and
   `sudo systemctl restart wall-control`. The lights show up in the Lights card.
Keep `devices.json` / `tinytuya.json` out of git (they are ignored): they hold the keys to your lights.
The **Living room** group (default: "Living room lights" + "White LED strip") is what the 🌙 button and the
nightly schedule switch off; tap the 🏠/＋ tag next to a light in the app to add or remove it from the group.
**At home**, press 🔍 Find lights once (or run it again if a light's address changes): it scans the Wi-Fi and
caches each light's IP address and protocol version. Sensors, the gateway and Zigbee sub-devices are never
controlled. To use only some devices, create `panel_setup/lights.json` with `{"only": ["Living room lights"]}`.
Give each light a fixed address in your router (DHCP reservation), or re-run the wizard if one moves.
Re-pairing a light in the Smart Life app changes its local key - re-run the wizard then.

## Mirror extras (app: "Mirror voice & people", Mirror mode, Dedications)
- **Tone & language**: slider kind -> roast and a language (English, Deutsch, Züridütsch, Français, Drama queen);
  applies to the very next photo, no restart (`mirror_settings.json`).
- **Smile sparkles**: smile ratio from the face landmarks (`moods.py`; tune with env `MIRROR_SMILE_RATIO`, default 0.90 -
  higher = needs a bigger smile). Switch in the app.
- **People**: "Learn my face" needs mirror mode running (it looks through the camera ~5 s). Stored only as numbers in
  `faces.json` on the Pi. "Learn frequent faces" is OFF by default; it suggests unnamed regulars after 5 sightings on 2 days.
  Models: `assets/models/get_models.sh` (the bootstrap script runs it).
- **Aura** / **Pixel selfie** buttons (mirror mode): AI colour reading with the wall glowing in that colour; 48x48 sprite portrait.
- **Nobody around**: after N quiet minutes (default 10) the mirror shows Lava & Coral; motion or a face brings the silhouette back only if "Motion or a face brings the mirror back" is ticked in the app (default off: only a button does).
- **Dedications**: guests open `http://<pi>/d` (or scan the QR from the app) - messages scroll across the bottom of the wall.
  No filtering by design; pause / delete / clear in the app. Off until you switch it on.
- **Art**: *Shapes* (13 thin generative line patterns; also available as music styles) and *Light Art* (stained glass,
  Julia set, kaleidoscope, long-exposure trails, nebula).

## Music mode: the party slider
The **Party level** slider (0-100 %) sets everything: at 0 the art just breathes (slow painterly
pieces, a few-percent swell with the bass, never a flash); towards 100 it becomes neon geometry
whose motion follows the beat, with scene changes on 4-bar boundaries. Brightness never pulses on
the beat. Optional "let the wall listen" (under More) estimates the level from loudness, beat lock,
tempo and bass (`display/intensity.py`). The app shows the live microphone (level, bass, detected
beats) next to the Sensitivity slider: raise it if the trace stays flat while music plays.
"Video loops only" plays the clip library (pick one, or Auto); "Music affects the loops" sets how.

## AI (Claude)
All AI features call the Anthropic API through `ai_client.ask()` (model `config.AI_MODEL`, low
effort, server-side refusal fallbacks, structured JSON where needed). Put `ANTHROPIC_API_KEY=...`
in `.env` on the laptop and copy it to the Pi (`scp .env pi@<ip>:~/magic-mirror/.env`), then
restart `wall-control`. Without a key every feature falls back to built-in text/rules.

## Video loops
`tools/make_loops.py <folders>` converts any video folder to 192 × 192 clips in `assets/loops/`
(with an index of motion/brightness the curator uses); deploy copies them. The current library is
abstract Beeple clips (CC) and calm Mixkit footage; originals live in `~/Movies/VJ Loops/`.

## The Fortuna gallery (public feed)

Every day's piece is published to https://fionnf.github.io/magic-mirror/ (feed, one page per
piece, RSS at `feed.xml`). Each post runs the piece's own shader live in the visitor's browser.

How a day goes:
1. Around 05:00 Claude composes the piece after looking at the Pinterest mood board
   (`WALL_MOODBOARD`, read via the board's public RSS feed).
2. A second Claude call, the curator, looks at rendered stills. Anything under 7/10 goes back with
   a note, up to four tries, and the best one is hung.
3. The wall publishes it (`display/publish.py` writes `gallery/` through the GitHub API, and the
   Pages workflow rebuilds the site). That needs `GALLERY_TOKEN` in `.env`.
4. At midnight the piece is finalised with the day's listening. Claude writes the post (caption +
   alt text) from the final still, and the update is published. Song titles never leave the Pi.

By hand: `python3 -m display.publish 2026-10-09`. Preview the site locally:
`python3 tools/build_gallery.py --from assets/daily --out /tmp/site`.

## Receipt printer: here, on another Pi, Wi-Fi or Bluetooth

`WALL_PRINTER` in `.env` says where the printer is (default `usb`: plugged into the wall's Pi).

| Setup | `WALL_PRINTER` |
|---|---|
| USB on the wall's Pi | `usb` |
| USB on a second Pi elsewhere in the room | `http://<that-pi>.local:8631` + the same `PRINT_KEY` on both |
| Wi-Fi / Ethernet ESC/POS printer | `tcp://<printer-ip>:9100` |
| Bluetooth printer (paired, bound to `/dev/rfcomm0`) | `serial:/dev/rfcomm0` |

Second Pi: copy `print_out.py`, `tools/print_server.py` and `tools/install_print_server.sh` into
one folder on it and run `PRINT_KEY=<secret> ./install_print_server.sh`. It installs a service
on port 8631, and the app's More tab shows whether the printer answers.

Quality always beats speed. Paper is 57 mm, so the printable width is 384 dots at 203 dpi, the
printer's full resolution. Pictures are Atkinson-dithered at exactly that width and sent as native
raster. The head prints slowly and hot (`PRINTER_HEAT`, `PRINTER_DENSITY`, `PRINTER_DITHER` env
vars in `print_out.py` if a printer needs tuning).

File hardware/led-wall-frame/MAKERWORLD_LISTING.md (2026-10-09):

# MakerWorld listing – copy & paste

**Title:** Modular LED Wall Frame for 12 × P4 64×64 panels – Raspberry Pi inside, camera pod, support-free

**Category:** Gadgets / Electronics (or Household → Wall mounts)

**Tags:** LED matrix, HUB75, P4, 64x64, LED wall, magic mirror, Raspberry Pi 5, Raspberry Pi 4, Pi camera, Logitech C270, frame, wall mount, modular, dovetail, support-free, PETG, OpenSCAD, parametric

**Cover image:** `images/01_front.png` · then `02_rear`, `03_rear_exploded`, `04_pi_tray`, `05_psu_tray`, `06_camera_module3_pod`, `07_c270_box_option`, `08`–`10` plates, `11_touch_box`, `12_c270_box_snap_lid` (add a photo of your build as soon as you have one).

---

## Description

Turn twelve cheap P4 64×64 LED panels (256 × 256 mm, the common AliExpress `P4-2121-64X64-32S` type) into a clean 77 × 102 cm LED wall – with the Raspberry Pi, HUB75 shield and 5 V power supply hidden inside the frame, and a small camera pod on top for interactive / magic-mirror projects.

**Highlights**
- Fully modular: 20 nodes screw into the panels' brass inserts, 31 dovetailed rails lock them into one rigid lattice.
- 84 × M3 × 20 countersunk screws – every corner and mid-edge insert is used, heads sit flush.
- 46 mm deep: room for a Raspberry Pi 4/5 + HUB75 shield and a 5 V 40 A supply (CZCL A-200AF-5) inside.
- Snug press-fit trays for the Pi and the PSU – they plug into the rail windows, no tools.
- Camera pod for Raspberry Pi Camera Module 3 (portrait, 15° down) or a box for the Logitech C270 with a snap-on lid.
- Bonus: 40 × 40 × 10 mm touch button box (TTP223 / 25 mm pad) with a 0.6 mm front skin.
- Built-in wall keyholes (optional ear brackets).
- Cable windows big enough for HUB75 ribbon plugs.
- **No supports anywhere.** Every plate fits a 250 × 220 mm bed.
- Parametric OpenSCAD source included.

**What to print** – see the plate list in the files: `00` fit test first, then `01`–`06` frame, one `07` Pi holder, `08` PSU tray, `09` or `10` camera, optional `11` touch box and `12` wall ears. ≈ 2 kg PETG.

**Print settings:** PETG, 0.2 mm layers, 5 walls, 40 % gyroid, no supports, no brim.

**Hardware:** 84 × M3 × 20 DIN 7991 countersunk + long 2 mm hex key · 2 + 4 × M3 × 12 (camera pod) · 4 × M2.5 × 6 (Pi) · 4 × M2 × 5 (camera) · 2 zip ties ≥ 300 mm · 6 wall screws (head ≤ 8.2 mm).

**Assembly:** panels face down → nodes on the corner inserts → drop the rails in (dovetails) → screw down → press in the Pi and PSU trays → camera pod on the top rail → hang on 6 screws.

**Safety:** the supply runs on mains – cover the AC terminals, strain-relieve the cable and fit a fuse/switch outside the frame. One 200 W supply is short for 12 panels at full white, so limit brightness in software or add a second supply.

---

## Print profile notes (per plate, for MakerWorld "print profiles")

| Plate | Time est.* | Filament (≈) |
|---|---|---|
| 00 fit test | short | 55 g |
| 01 junction nodes | medium | 240 g |
| 02 edge + corner nodes | medium | 215 g |
| 03–06 rails (each) | long | 320–400 g |
| 07 Pi tray / compact holder | short | 50 / 30 g |
| 08 PSU tray | short | 70 g |
| 09 camera pod / 10 C270 box | short | 30 / 60 g |

\*Slice once in Bambu Studio and publish the plates as print profiles to get exact times.

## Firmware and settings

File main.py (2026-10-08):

"""Magic Mirror — main state machine.

Runs on real hardware by default, or with --sim using the simulator.

The live silhouette is ALWAYS rendered as the background of whatever the mirror
is showing — idle, thinking, or speaking. A dedicated thread continuously
captures camera frames, extracts the silhouette mask, and stores the latest
rendered overlay in `_live_silhouette` for the display loop to composite.
"""
import argparse
import signal
import sys
import time
import math
import threading
import enum
from typing import Optional
from PIL import Image, ImageDraw, ImageOps

from dotenv import load_dotenv
load_dotenv()

import config
from display import animations, text_renderer, silhouette as silhouette_render
from api import MirrorAPI
from mqtt_bridge import MQTTBridge


class State(enum.Enum):
    IDLE = "IDLE"
    TRIGGERED = "TRIGGERED"
    CAPTURING = "CAPTURING"
    AI_WAITING = "AI_WAITING"
    DISPLAYING = "DISPLAYING"
    FADE_OUT = "FADE_OUT"
    BOOTH = "BOOTH"


class NullButton:
    """Stand-in when no touch sensor is wired up. Triggers come from the
    dashboard/API, MQTT, or --auto."""
    def __init__(self, short_cb=None, long_cb=None):
        pass

    def handle_event(self, event):
        pass

    def shutdown(self):
        pass


def start_auto_trigger(mirror, every_sec: float, booth_every: int = 0,
                       count: int = 0):
    """Press the 'button' every N seconds while idle (hands-free testing).
    count > 0 stops after that many presses; the mirror then stays idle."""
    def loop():
        n = 0
        while not mirror._stop.wait(every_sec):
            if count and n >= count:
                if mirror.state == State.IDLE:
                    print(f"[AUTO] done: {count} cycles")
                    return
                continue
            if mirror.state == State.IDLE:
                n += 1
                if booth_every and n % booth_every == 0:
                    mirror._booth_event.set()
                else:
                    mirror._trigger_event.set()
    threading.Thread(target=loop, daemon=True, name="auto-trigger").start()


class MagicMirror:
    def __init__(self, matrix, camera, button_factory, strip, printer,
                 sim_mode: bool, no_api: bool):
        self.matrix = matrix
        self.camera = camera
        self.strip = strip
        self.printer = printer
        self.sim_mode = sim_mode
        self.no_api = no_api
        self.state = State.IDLE
        self._trigger_event = threading.Event()
        self._booth_event = threading.Event()
        self._stop = threading.Event()
        self.button = button_factory(self._on_button, self._on_long_press)
        self._latest_frame = None              # last raw camera frame (for AI)
        self._live_silhouette: Optional[Image.Image] = None  # PIL RGB, full canvas
        self._silhouette_lock = threading.Lock()
        self._silhouette_version = 0           # bumps when the silhouette changes
        self._capture_thread: Optional[threading.Thread] = None
        self._overlay_text: Optional[str] = None   # pushed from dashboard
        self._overlay_image: Optional[Image.Image] = None
        self._aura_event = threading.Event()
        self._pixel_event = threading.Event()
        self._sparkle = None                       # (cx, cy normalised, until_monotonic)
        self._sparkle_check = 0.0
        self._last_presence = time.monotonic()      # last time someone/something moved in front
        self._prev_small = None
        self._idle_min = (10, False, 0.0)           # (minutes, wake_on_motion, when read) cache of the settings
        self._info = {"names": [], "smiling": False, "faces": 0}   # who/what the last photo saw

    # ---- button ----

    def _on_button(self):
        if self.state == State.IDLE:
            self._trigger_event.set()
        else:
            print(f"[STATE] touch ignored in state {self.state.name}")

    def _on_long_press(self):
        if self.state == State.IDLE:
            print("[STATE] long press -> photobooth")
            self._booth_event.set()
        else:
            print(f"[STATE] long press ignored in state {self.state.name}")

    # ---- state ----

    def _set_state(self, s: State):
        self.state = s
        print(f"[STATE] {s.name}")
        if hasattr(self.matrix, "set_state_label"):
            self.matrix.set_state_label(s.name)

    # ---- continuous silhouette capture ----

    def _capture_loop(self):
        interval = 1.0 / max(1, config.LIVE_SILHOUETTE_FPS)
        while not self._stop.is_set():
            t0 = time.monotonic()
            try:
                frame = self.camera.capture_frame()
                self._latest_frame = frame
                self._note_motion(frame)
                self._look_for_smile(frame)
                mask = self.camera.extract_silhouette(
                    frame, getattr(self.camera, "_background", None))
                img = silhouette_render.render_silhouette(mask)
                with self._silhouette_lock:
                    self._live_silhouette = img
                    self._silhouette_version += 1
                # tell the strip where the silhouette is so its hue band can
                # follow the person horizontally
                try:
                    import numpy as np
                    cols = np.where(mask.any(axis=0))[0]
                    if len(cols) > 0:
                        centroid_x = float(cols.mean()) / max(1, mask.shape[1])
                        self.strip.set_centroid(centroid_x)
                except Exception:
                    pass
            except Exception as e:
                print(f"[CAPTURE] {e}")
                time.sleep(0.5)
                continue
            dt = time.monotonic() - t0
            time.sleep(max(0.0, interval - dt))

    def _note_motion(self, frame):
        """Presence = the picture is changing (someone moves) - cheap 40x30 frame difference."""
        try:
            import cv2
            small = cv2.resize(cv2.cvtColor(frame, cv2.COLOR_BGR2GRAY), (40, 30)).astype("float32")
            if self._prev_small is not None and abs(small - self._prev_small).mean() > 2.5:
                self._last_presence = time.monotonic()
            self._prev_small = small
        except Exception:
            self._last_presence = time.monotonic()

    def _idle_art_wanted(self):
        """True when nobody has been in front of the mirror for the configured time."""
        mins, wake, read = self._idle_min
        now = time.monotonic()
        if now - read > 5.0:
            try:
                import mirror_settings
                st = mirror_settings.load()
                mins, wake = st["idle_art_minutes"], st["wake_on_motion"]
            except Exception:
                pass
            self._idle_min = (mins, wake, now)
        if mins <= 0:
            return False
        if getattr(self, "_art_on", False) and not wake:
            return True                  # art stays until a button/trigger (run() clears _art_on)
        return now - self._last_presence > mins * 60

    def _look_for_smile(self, frame):
        """About 3x a second: if the main face is smiling, sparkle around it for 2 seconds."""
        now = time.monotonic()
        if now - self._sparkle_check < 0.33 or self.state != State.IDLE:
            return
        self._sparkle_check = now
        try:
            import mirror_settings
            if not mirror_settings.load()["smile"]:
                return
            import smartcrop, moods
            rows = [r for r in smartcrop.find_face_rows(frame) if min(r[2], r[3]) >= 40]
            if not rows:
                return
            self._last_presence = now                    # a face is there
            r = max(rows, key=lambda r: r[2] * r[3])
            if moods.is_smiling(r):
                h, w = frame.shape[:2]
                cx = (r[0] + r[2] / 2) / w
                if config.SILHOUETTE_MIRROR:
                    cx = 1.0 - cx
                self._sparkle = (cx, (r[1] + r[3] / 2) / h, now + 2.0)
        except Exception as e:
            print(f"[SMILE] {e}")

    def _silhouette(self, dim: float = 1.0) -> Image.Image:
        with self._silhouette_lock:
            img = self._live_silhouette
        if img is None:
            return Image.new("RGB", (config.TOTAL_WIDTH, config.TOTAL_HEIGHT))
        if dim >= 0.999:
            return img.copy()
        return Image.eval(img, lambda v: int(v * dim))

    # ---- behaviours ----

    def _ai_call(self, frame):
        if self.no_api:
            time.sleep(1.0)
            return "The mirror dreams of electric sheep."
        import ai_client
        return self._shorten(ai_client.get_mirror_message(frame, self._hint()))

    @staticmethod
    def _shorten(text):
        """Safety net: strip quotes and cap the reply at AI_MAX_WORDS words."""
        if not text:
            return text
        words = text.strip().strip('"\u201c\u201d').split()
        if len(words) <= config.AI_MAX_WORDS:
            return " ".join(words)
        return " ".join(words[:config.AI_MAX_WORDS]).rstrip(",;:-") + "..."

    def _flash_white(self, ms: int):
        # short white flash on top of the silhouette as touch feedback
        white = Image.new("RGB", (config.TOTAL_WIDTH, config.TOTAL_HEIGHT), (255, 255, 255))
        self.matrix.draw(white)
        time.sleep(ms / 1000.0)

    def _fade_out(self, base: Image.Image, seconds: float):
        """Fade `base` (the text+silhouette composite) down to just the live
        silhouette — the mirror never goes fully black while someone is there.
        """
        steps = max(1, int(seconds * config.IDLE_ANIMATION_FPS))
        interval = 1.0 / config.IDLE_ANIMATION_FPS
        for i in range(steps, -1, -1):
            alpha = i / steps
            faded = Image.eval(base, lambda v: int(v * alpha))
            # composite over current live silhouette so it bleeds through
            live = self._silhouette()
            combined = Image.blend(live, faded, alpha)
            self.matrix.draw(combined)
            time.sleep(interval)

    def _run_idle_until_trigger(self) -> str:
        """Block until short or long press. Returns 'short' or 'long'."""
        interval = 1.0 / config.IDLE_ANIMATION_FPS

        last_key = None
        while not self._stop.is_set():
            if self._booth_event.is_set():
                self._booth_event.clear()
                return "long"
            if self._aura_event.is_set():
                self._aura_event.clear()
                return "aura"
            if self._pixel_event.is_set():
                self._pixel_event.clear()
                return "pixel"
            if self._trigger_event.is_set():
                self._trigger_event.clear()
                return "short"

            if self._idle_art_wanted():
                # nobody around for a while: show slow art instead of the (empty) silhouette
                if not getattr(self, "_art_on", False):
                    print("[IDLE] nobody around - showing art")
                    self._art_on = True
                from display import art
                self.matrix.draw(art.frame_lava_coral(time.monotonic()))
                last_key = None
                time.sleep(1.0 / 15)
                continue
            if getattr(self, "_art_on", False):
                print("[IDLE] someone is back - silhouette")
                self._art_on = False

            # Only recompose + redraw when something visible changed (new
            # silhouette frame or a new overlay) — not on every tick.
            sp = self._sparkle
            sparkling = sp is not None and time.monotonic() < sp[2]
            key = (self._silhouette_version, id(self._overlay_image),
                   self._overlay_text, int(time.monotonic() * 8) if sparkling else None)
            if key != last_key:
                last_key = key
                canvas = self._silhouette()
                if self._overlay_image is not None:
                    try:
                        canvas.paste(self._overlay_image, (0, 0))
                    except Exception:
                        pass
                elif self._overlay_text is not None:
                    try:
                        text_renderer.render_static_text(canvas, self._overlay_text)
                    except Exception:
                        pass
                if sparkling:
                    try:
                        from display import sparkle
                        sparkle.draw(canvas, sp[0] * config.TOTAL_WIDTH, sp[1] * config.TOTAL_HEIGHT,
                                     time.monotonic())
                    except Exception:
                        pass
                self.matrix.draw(canvas)
            time.sleep(interval)
        return "short"

    def _do_countdown(self, seconds: int = 3):
        """Show a 3-2-1 countdown centred on top of the live silhouette,
        with the strip breathing in sync."""
        self.strip.set_mode("countdown")
        interval = 1.0 / config.IDLE_ANIMATION_FPS
        for n in range(seconds, 0, -1):
            end = time.monotonic() + 1.0
            while time.monotonic() < end and not self._stop.is_set():
                canvas = self._silhouette(dim=config.SILHOUETTE_DIM_FACTOR)
                text_renderer.render_static_text(canvas, str(n),
                                                 colour=(255, 255, 255))
                self.matrix.draw(canvas)
                time.sleep(interval)

    def _grab_photo(self):
        """A full-width frame cut to portrait around the people (smart crop). Falls back to
        the last live frame (already a centred portrait crop) if the camera hiccups."""
        try:
            raw = self.camera.capture_frame(raw=True)
        except TypeError:                        # a camera without raw support
            return self.camera.capture_frame()
        import smartcrop
        rows = smartcrop.find_face_rows(raw)
        self._read_faces(raw, rows)
        faces = [(float(r[0]), float(r[1]), float(r[2]), float(r[3]), float(r[14])) for r in rows]
        frame, how = smartcrop.portrait_crop(raw, config.CAMERA_ASPECT,
                                             getattr(self.camera, "_background_raw", None), faces=faces)
        print(f"[CROP] portrait via {how}")
        return frame

    def _read_faces(self, raw, rows):
        """Who is in front of the mirror and are they smiling (names only for people who were
        enrolled in the app; never anything else is stored)."""
        info = {"names": [], "smiling": False, "faces": len(rows)}
        try:
            import mirror_settings
            st = mirror_settings.load()
            import moods
            big = [r for r in rows if min(r[2], r[3]) >= 40]
            if st["smile"] and big:
                info["smiling"] = moods.is_smiling(max(big, key=lambda r: r[2] * r[3]))
            if st["recognise"]:
                import faces
                if faces.available():
                    book = getattr(self, "_facebook", None) or faces.FaceBook()
                    self._facebook = book
                    if book.people():
                        seen = book.observe(raw, rows, learn=st["learn_faces"])
                        info["names"] = [n for _, n, _ in seen if n]
        except Exception as e:
            print(f"[FACES] skipped: {e}")
        self._info = info
        print(f"[FACES] {info}")

    def _hint(self):
        """Facts for the AI line, e.g. 'The person is called Fionn. They are smiling.'"""
        i, parts = self._info, []
        if i["names"]:
            parts.append("The person is called " + " and ".join(dict.fromkeys(i["names"])) + ".")
        if i["smiling"]:
            parts.append("They are smiling.")
        if i["faces"] > 1:
            parts.append(f"There are {i['faces']} people in the picture.")
        return " ".join(parts)

    def _do_trigger_capture(self):
        """Single-shot capture: countdown then grab the latest frame from the
        live thread — no LED flash. Booth mode has its own _capture_with_flash
        that does illuminate the subject."""
        self._set_state(State.TRIGGERED)
        self._do_countdown(3)
        self._set_state(State.CAPTURING)
        try:
            frame = self._grab_photo()
        except Exception as e:
            print(f"[CAPTURE] direct grab failed, falling back: {e}")
            frame = self._latest_frame
        if self.sim_mode:
            print("[SIM] Camera: captured frame (no flash)")
        return frame

    def _do_ai_wait(self, frame):
        self._set_state(State.AI_WAITING)
        self.strip.set_mode("thinking")
        if self.sim_mode:
            print("[SIM] API call started (threaded)")
        result = {"text": None}

        def worker():
            result["text"] = self._ai_call(frame)
        t = threading.Thread(target=worker, daemon=True)
        t.start()

        min_show_until = time.monotonic() + config.SILHOUETTE_DISPLAY_SEC
        hard_deadline = time.monotonic() + config.AI_TIMEOUT_SEC + 2.0
        interval = 1.0 / config.IDLE_ANIMATION_FPS
        import numpy as np
        # Single persistent generator so its internal t counter advances each
        # frame and the dots actually pulse. Composite with the live silhouette
        # via per-channel max so the background tracks the person.
        dots_gen = animations.thinking_dots()
        while t.is_alive() or time.monotonic() < min_show_until:
            base = self._silhouette()
            a = np.asarray(base, dtype=np.uint8)
            b = np.asarray(next(dots_gen), dtype=np.uint8)
            self.matrix.draw(Image.fromarray(np.maximum(a, b), "RGB"))
            if time.monotonic() > hard_deadline:
                break
            time.sleep(interval)
        t.join(timeout=0.5)
        text = result["text"] or config.AI_FALLBACK_MESSAGE
        if self.sim_mode:
            print(f"[SIM] API response: {text!r}")
        return text

    def _do_display(self, text: str):
        self._set_state(State.DISPLAYING)
        self.strip.set_mode("displaying")
        if self.sim_mode:
            print("[SIM] Scrolling text...")

        interval = 1.0 / config.IDLE_ANIMATION_FPS
        # Text frames are transparent except for the outlined message; paste
        # them over the *current* (dimmed) live silhouette so the person stays
        # visible underneath while the outline keeps the text readable.
        gen = text_renderer.scroll_text_frames(text, rgba=True)
        for text_frame, finished in gen:
            canvas = self._silhouette(dim=config.SILHOUETTE_DIM_FACTOR)
            canvas.paste(text_frame, (0, 0), text_frame)
            self.matrix.draw(canvas)
            if finished:
                break
            time.sleep(interval)
        # return the dim live silhouette for the fade-out to consume
        return self._silhouette(dim=config.SILHOUETTE_DIM_FACTOR)

    def _capture_with_flash(self):
        """Run the same illumination flash as a single-shot capture and
        return the captured frame. Sets strip back to 'thinking' after."""
        self.strip.set_mode("capture_flash")
        white = Image.new("RGB", (config.TOTAL_WIDTH, config.TOTAL_HEIGHT),
                          (255, 255, 255))
        self.matrix.draw(white)
        time.sleep(config.PHOTO_FLASH_PRE_MS / 1000.0)
        try:
            frame = self._grab_photo()
        except Exception as e:
            print(f"[CAPTURE] direct grab failed: {e}")
            frame = self._latest_frame
        time.sleep(config.PHOTO_FLASH_POST_MS / 1000.0)
        return frame

    def _booth_display_strip(self, strip_image):
        """Show the booth strip scaled to fit the matrix for BOOTH_DISPLAY_SEC.
        Aspect is preserved; height-bound to TOTAL_HEIGHT so the photos read."""
        import numpy as np
        W, H = config.TOTAL_WIDTH, config.TOTAL_HEIGHT
        src = strip_image.convert("L")
        # height-bound scaling — photo strips are far taller than they are wide
        scale = H / src.height
        new_w = max(1, int(round(src.width * scale)))
        new_h = H
        if new_w > W:
            scale = W / src.width
            new_w = W
            new_h = int(round(src.height * scale))
        thumb = src.resize((new_w, new_h), Image.LANCZOS)
        # invert so dark print pixels show as lit panel pixels
        thumb = ImageOps.invert(thumb)
        # convert to RGB on a black canvas, centred
        canvas = Image.new("RGB", (W, H), (0, 0, 0))
        x = (W - new_w) // 2
        y = (H - new_h) // 2
        canvas.paste(thumb.convert("RGB"), (x, y))
        # subtle outline frame around the strip area
        d = ImageDraw.Draw(canvas)
        d.rectangle([x - 1, y - 1, x + new_w, y + new_h],
                    outline=(255, 200, 80))
        end = time.monotonic() + config.BOOTH_DISPLAY_SEC
        while time.monotonic() < end and not self._stop.is_set():
            self.matrix.draw(canvas)
            time.sleep(0.08)

    def _show_booth_prompt(self, text: str, seconds: float):
        """Display a pose direction big on the matrix for `seconds`."""
        import textwrap
        from display.text_renderer import _FONT, _text_size
        from PIL import ImageDraw as _ImageDraw
        W, H = config.TOTAL_WIDTH, config.TOTAL_HEIGHT

        # measure character width to pick a sensible wrap column
        probe = Image.new("RGB", (W, H))
        d = _ImageDraw.Draw(probe)
        char_w, _ = _text_size(d, "M")
        cols = max(8, W // max(1, char_w))
        lines = textwrap.wrap(text, width=cols) or [text]
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

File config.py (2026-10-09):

import os
# Panel hardware — up to 12× 64x64 panels (256 mm square) in a 3-wide x 4-tall
# portrait layout, all on ONE chain from the Adafruit HAT.
PANEL_ROWS = 64
PANEL_COLS = 64
PANELS_WIDE = 3
PANELS_TALL = int(__import__("os").environ.get("WALL_PANELS_TALL", 3))   # 3 now; the full wall is 4 (192 x 256).
#                 WALL_PANELS_TALL=4 previews the full wall in the simulator; set 4 here when the row is wired
CHAIN_LENGTH = PANELS_WIDE * PANELS_TALL
PARALLEL = 1
# The built-in rpi-rgb-led-matrix mappers can't do a 3-column serpentine, so
# the driver runs the chain as a flat (64*12) x 64 strip and remaps the image
# in software (see led_matrix.py). Leave PIXEL_MAPPER empty.
PIXEL_MAPPER = ""
# Physical chain order, as (col, row) of each panel starting at the one the
# HAT cable plugs into. Currently a row serpentine starting at the bottom-left
# (see below). Edit to match your wiring; check with
# panel_setup/display_test.py --pattern numbers.
PANEL_CHAIN_ORDER = [            # row serpentine from the bottom-left, any number of rows
    (c if (PANELS_TALL - 1 - r) % 2 == 0 else PANELS_WIDE - 1 - c, r)
    for r in range(PANELS_TALL - 1, -1, -1) for c in range(PANELS_WIDE)
]
# 3 rows: (0,2) (1,2) (2,2) | (2,1) (1,1) (0,1) | (0,0) (1,0) (2,0)  - chain 0-2, 3-5, 6-8
# ^ measured on the wall (photo 2026-10-07): the cable enters at the BOTTOM-LEFT
#   panel and snakes by rows. Add the 4th row here when it is connected.
# Per-panel rotation in degrees (0/90/180/270) keyed by chain index, for
# panels mounted upside down. Missing = 0.
# Middle row (chain 3-5) is mounted upside down.
PANEL_ROTATE = {3: 180, 4: 180, 5: 180}
SCAN_RATE = 32  # most 64x64 panels are 1/32 scan — confirm from sticker
# CONFIRMED WORKING on Pi 4B (Fortuna) with the P3 64x64 FM6124 panels:
#   hardware_mapping "regular", gpio_slowdown 3, panel_type FM6126A, pwm_bits 7
# (FM6124 panels need the FM6126A init sequence, otherwise they stay dark/garbled.)
HARDWARE_MAPPING = "regular"
GPIO_SLOWDOWN = 7   # 7 = cleanest first panel (fewer data errors); refresh ~59.6 Hz max, locked at 58
                    # history: 3 streaky, 4 better, 5 good, 6 clean (~67 Hz), 8 = ~57 Hz banding returns
                    # 8 = ~57 Hz banding returns. 6-bit at slowdown 6 = ~77 Hz but colour banding.
MATRIX_PANEL_TYPE = "FM6126A"
# Long chain => low refresh rate. These are the main tuning knobs:
MATRIX_BRIGHTNESS = int(__import__("os").environ.get("WALL_BRIGHTNESS", 40))  # 0-100; the web panel sets WALL_BRIGHTNESS
# Power budget. PSU is 40 A @ 5 V; keep headroom for the Pi and wiring losses.
# The driver estimates current per frame from pixel values x brightness and
# scales the frame down if it would exceed MATRIX_MAX_AMPS.
MATRIX_MAX_AMPS = 28.0
# Conservative full-white draw of ONE 64x64 panel at 100% brightness (typical
# 3-4 A; measure yours and adjust).
MATRIX_AMPS_PER_PANEL = 4.0
MATRIX_PWM_BITS = 7            # 1-11; fewer bits = much higher refresh
MATRIX_PWM_DITHER_BITS = 0      # 0-2: smoother gradients at low pwm_bits, costs refresh
MATRIX_PWM_LSB_NS = 130        # lower = faster refresh (try 100-300)
MATRIX_REFRESH_LIMIT_HZ = 58   # lock refresh: animations at 29 fps = exactly 2 refreshes per frame (no judder)
MATRIX_MULTIPLEXING = 0        # change if the image looks striped/scrambled
MATRIX_ROW_ADDRESS_TYPE = 0    # 64x64 panels with ABCDE addressing: usually 0
MATRIX_SHOW_REFRESH = False    # print refresh rate to stdout

# Per-panel colour calibration (written by panel_setup/calibrate_colour.py).
# Per-panel, per-channel gains applied through a 256-entry LUT; missing file or
# MATRIX_APPLY_PANEL_GAINS=False = no correction.
PANEL_GAINS_FILE = "panel_setup/colour_calibration.json"
MATRIX_APPLY_PANEL_GAINS = True

# Total canvas: 3 panels wide x 4 panels tall = 192 wide x 256 tall (portrait)
TOTAL_WIDTH = PANELS_WIDE * PANEL_COLS
TOTAL_HEIGHT = PANELS_TALL * PANEL_ROWS

# GPIO — capacitive touch sensor (e.g. TTP223) wired to BUTTON_PIN.
# Most capacitive touch modules output HIGH on touch; set TOUCH_ACTIVE_HIGH=True.
# If your module is configured for active-LOW output, flip this.
BUTTON_PIN = 25
BUTTON_DEBOUNCE_MS = 300
TOUCH_ACTIVE_HIGH = True
# Many capacitive modules drive the line themselves and need no pull resistor.
# Set to "up", "down", or "off" depending on your module's output stage.
TOUCH_PULL = "down"

# Camera
CAMERA_WARMUP_SEC = 2
FRAME_WIDTH = 640
FRAME_HEIGHT = 480
# Every captured frame is centre-cropped to this width/height ratio, so the AI,
# the receipt and the silhouette all see the same portrait picture.
CAMERA_ASPECT = 3 / 4
# Photos (AI / receipt / booth) are cut to portrait around the people (face detector, then motion,
# then centre). Set False to always centre-crop.
SMART_CROP = os.environ.get("WALL_SMART_CROP", "1") != "0"   # the web app sets WALL_SMART_CROP
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

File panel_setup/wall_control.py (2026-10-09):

"""Wall control — one web page (on the Pi) to choose what the LED wall shows.

    sudo python3 panel_setup/wall_control.py            # http://<pi>/  (port 80)
    sudo python3 panel_setup/wall_control.py --port 8080

It is the only program that drives the panels: each mode runs as a child
process (play.py <anim>, main.py for the mirror, wheel.py for a spin), the
controller stops the old one before starting the next, restarts a mode that
crashes, runs playlists, and remembers the choice across reboots
(panel_setup/wall_state.json). Install as a boot service with
panel_setup/install_control.sh.
"""
import argparse
import json
import os
import signal
import subprocess
import sys
import threading
import time
import urllib.error
import urllib.request

HERE = os.path.dirname(os.path.abspath(__file__))
ROOT = os.path.dirname(HERE)
sys.path.insert(0, ROOT)
STATE_FILE = os.path.join(HERE, "wall_state.json")
LOG_DIR = os.path.join(HERE, "logs")
WEB_DIR = os.path.join(HERE, "web")
THUMB_DIR = os.path.join(WEB_DIR, "thumbs")
PY = sys.executable or "/usr/bin/python3"

MODES = [
    # id, category, title, description
    ("lava", "Art", "Lava & Coral", "Coral, bloom, cells and slow bioluminescence"),
    ("shapes", "Art", "Shapes", "Flow dots, woven grids, ripples: thin glowing lines"),
    ("daily", "Art", "Art of the day", "A new piece every day, made for this wall"),
    ("shaders", "Art", "Shaders", "Conic tiles, aperture, eclipse, halo, glass and more"),
    ("artsy", "Art", "Artsy", "Marbling, op-art stripes, oil slick, a drifting Mondrian"),
    ("glass", "Art", "Light Art", "Stained glass, long-exposure trails, nebula"),
    ("art", "Art", "Art Gallery", "Ink flow, colour fields, moiré"),
    ("pride", "Shows", "Pride Show", "Disco ball, HOUSE FORTUNA, people nearby, vortex, heart"),
    ("dewa", "Shows", "Dewa's Story", "Edelweiss flight attendant, a date at every layover"),
    ("maeva", "Shows", "Maeva in Zürich", "Tram at 8:00:00, the Limmat, Sprüngli, sledging"),
    ("welcome", "Shows", "Welcome", "Welcome to HOUSE FORTUNA, wheel of fortune"),
    ("cow", "Shows", "Dewa is a cow", "A message card"),
    ("music", "Live", "Music", "Art that breathes with the music in the room"),
    ("ambient", "Live", "Art + trams", "Lava & Coral with a small Rennweg tram strip"),
    ("trams", "Live", "Tram board", "Live departures from Rennweg, split-flap style"),
]
MODE_IDS = {m[0] for m in MODES}
DEFAULT_STATE = {"mode": "lava", "brightness": 40, "playlist": None,
                 "camera_url": "http://192.168.1.217:8090/cam.mjpg", "camera": "stream",
                 "mirror_auto": 0, "smart_crop": True, "art_speed": 0.12}


# ------------------------------------------------------------------ state ---

def load_state():
    try:
        with open(STATE_FILE) as f:
            s = json.load(f)
        return {**DEFAULT_STATE, **s}
    except Exception:
        return dict(DEFAULT_STATE)


def save_state(s):
    tmp = STATE_FILE + ".tmp"
    with open(tmp, "w") as f:
        json.dump(s, f, indent=2)
    os.replace(tmp, STATE_FILE)


# ----------------------------------------------------------------- runner ---

class Runner:
    def __init__(self):
        self.state = load_state()
        self.proc = None
        self.current = None          # what is running now (mode id, "mirror", "wheel", "off")
        self.since = time.time()
        self.lock = threading.RLock()
        self.restarts = []
        self.error = ""
        self.oneshot_resume = None
        self.playlist_idx = 0
        self.playlist_next = 0.0
        os.makedirs(LOG_DIR, exist_ok=True)
        threading.Thread(target=self._watch, daemon=True).start()

    # -- commands
    def _cmd(self, what):
        if what in MODE_IDS:
            return [PY, "panel_setup/play.py", what, "--fps", "29"]
        if what == "mirror":
            cmd = [PY, "-u", "main.py", "--no-touch", "--no-mqtt"]
            if os.environ.get("WALL_SIM"):
                cmd += ["--sim", "--camera", "webcam"]           # laptop: pygame window + its webcam
            elif self.state.get("camera") == "stream" and self.state.get("camera_url"):
                cmd += ["--camera-url", self.state["camera_url"]]
            elif self.state.get("camera") == "pi":
                pass                                    # real Pi camera
            else:
                cmd += ["--mock-camera", "static"]
            if int(self.state.get("mirror_auto") or 0) > 0:
                cmd += ["--auto", str(int(self.state["mirror_auto"]))]
            return cmd
        if what == "wheel":
            return [PY, "-u", "panel_setup/wheel.py", "--spins", "1"] + \
                   ([] if self.state.get("wheel_print", True) else ["--no-print"])
        return None

    def _stop_proc(self):
        p = self.proc
        self.proc = None
        if p and p.poll() is None:
            try:
                os.killpg(p.pid, signal.SIGINT)
                p.wait(timeout=8)
            except Exception:
                try:
                    os.killpg(p.pid, signal.SIGKILL)
                except Exception:
                    pass
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

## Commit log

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2026-05-18 Fix four bugs: numpy bool crash, static thinking-dots, dead variable, sample overflow
    - main.py: `self._latest_frame or None` raises ValueError when _latest_frame
    is a numpy ndarray (ambiguous truth value); drop the redundant `or None`.
    - main.py: thinking_dots generator was recreated every loop iteration,
    resetting its internal `t` counter to 0 each frame so the dots never
    animated. Now a single persistent generator is created before the loop and
    composited onto the live silhouette with np.maximum (same pattern as
    _do_display).
    - display/text_renderer.py: remove unused `last_yield = -1` variable in
    scroll_text_frames.
    - ai_client.py: random.sample raised ValueError if the filter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
    [ai_client.py, main.py]
2026-05-18 Implement led_strip, printer, cloud_uploader, and tests/test_printer
    Four modules referenced throughout the codebase but not yet present:
    led_strip.py
    SK6812 RGBW strip controller running in a background thread. Supports
    idle/countdown/thinking/displaying/fading/capture_flash modes; tracks the
    silhouette centroid with configurable exponential smoothing plus a
    two-frequency wobble so the band breathes when the subject is still.
    Simulator path forwards pixels to LEDSimulator.set_strip_pixels(); hardware
    path uses rpi_ws281x. Falls back to NullStrip on import error.
    printer.py
    render_booth_pil() composes a greyscale photo-strip (header, photos with
    captions, optional QR code,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
    [cloud_uploader.py, led_strip.py, printer.py]
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2026-05-19 Add Flask API and GitHub Pages dashboard
    Implements a Flask-based API server running as a daemon thread on port 5000 with CORS support for local network access from GitHub Pages. The dashboard provides:
    - Real-time online/offline status with 2-second polling
    - Mirror control: trigger (short press), photobooth (long press), power on/off
    - Settings management: scroll speed adjustment
    - Configurable local IP with localStorage persistence
    - Error handling and user-friendly UI
    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
    [api.py]
2026-05-19 Implement ZVV transit integration for idle mirror display
    Adds Zurich public transit (ZVV) departure display at the bottom of the mirror
    in dim mode during idle. The feature:
    - Fetches tram/bus departures from Rennweg stop via SBB Journey Planner API
    - Displays up to 3 departures in dim gray text at the bottom of the mirror
    - Caches results for 30 seconds to avoid API hammering
    - Falls back to mock data when the API is unavailable (works in simulator)
    - Refreshes continuously during idle mode
    The departures are displayed before the first touch and remain visible
    throughout idle periods.
    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
    [main.py]
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2026-05-19 Remove departures from main code, create dedicated ZVV API test script
    Removes tram departure display integration from:
    - main.py: idle display now just shows silhouette
    - test_full_sim.py: no longer fetches departures on startup
    Adds standalone test script tests/test_zvv_api.py for API testing with:
    - Configurable stop name, departure limit, timeout
    - Cached mode option (30s TTL)
    - Formatted output for verification
    - Clear success/error reporting
    The ZVV API remains available in zvv_client.py for future integration.
    Usage: python tests/test_zvv_api.py [--stop NAME] [--limit N] [--timeout S]
    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
    [main.py]
2026-05-19 Improve ZVV API error messages and User-Agent handling
    - Show full error details in API failure messages for better debugging
    - Use consistent User-Agent header (armv7l Linux) for all API endpoints
    - Makes it easier to diagnose why APIs are failing
    Current status:
    - HAFAS API: URLError (DNS issues in this environment)
    - Search.ch API: HTTP 403 Forbidden (possible IP blocking)
    - Both will work better on real Pi with internet connectivity
    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
2026-05-19 Document ZVV API access restrictions and switch to opendata.ch API
    Updated to use SBB opendata.ch API (https://transport.opendata.ch) which is
    the official public API for Swiss public transit. However, this API restricts
    programmatic access with 'Host not in allowlist' error.
    Most Swiss public transit APIs are restricted from programmatic access:
    - SBB opendata.ch: Blocks non-whitelisted hosts
    - Search.ch: Returns 403 Forbidden
    - myzvz.ch HAFAS: Returns DNS/connection errors
    To use real APIs in production, you would need:
    - SBB API key registration
    - Whitelisted host/referer
    - Web scraper (slower, unreliable)
    For now, the mock data fallback provides realistic test data that's always
    avail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
2026-05-20 Add MQTT bridge, photo store, overlay display, prompt editor, and photos gallery
    Backend:
    - mqtt_bridge.py: paho-mqtt bridge publishing status/preview, subscribing to commands
    - photo_store.py: local JPEG+JSON storage for receipts and booth strips
    - api.py: new endpoints — display/text, display/image, display DELETE,
    snapshot, prompts GET/POST, photos list/serve/reprint, /gallery route
    - main.py: _overlay_text/_overlay_image rendered in idle loop; MQTT bridge
    startup (--no-mqtt to skip); photo_store called after each cycle
    - config.py: MQTT_HOST, MQTT_PORT, MQTT_WS_PORT settings
    Dashboard (dashboard/index.html):
    - Dark theme, MQTT-first with HTTP fallback
    - Live camera preview via MQT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
    [api.py, config.py, main.py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]
2026-05-20 Fix GitHub Pages deployment and cross-origin navigation links
    - Remove paths filter from deploy-pages workflow so any master push triggers deployment
    - Gallery link in index.html defaults to relative photos.html (works from GitHub Pages); uses Pi /gallery when IP is configured
    - Back-link in photos.html defaults to relative index.html instead of / (wrong root on GitHub Pages)
    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
2026-05-21 Auto-select next free port when 5000 is taken (fixes macOS AirPlay conflict)
    api.start() probes ports 5000-5009 and binds to the first free one.
    test_full_sim.py prints the actual port after start.
    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
    [api.py]
2026-05-21 Fix /gallery 404 and macOS SDL2 SIGSEGV
    - api.py: use __file__-relative path for dashboard/ so it works regardless of CWD
    - requirements.txt: opencv-python → opencv-python-headless to eliminate duplicate
    libSDL2 bundled by opencv-python that conflicts with pygame on macOS, causing SIGSEGV
    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
    [api.py]
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2026-05-27 Fix install.sh for Debian trixie: libatlas-base-dev → libopenblas-dev
    libatlas-base-dev was removed in Debian 13 (trixie). libopenblas-dev
    is the current equivalent and available in all recent Pi OS releases.
    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
2026-05-27 Fix rpi-rgb-led-matrix build: use pip install instead of make build-python
    The build-python Makefile target was removed in recent versions.
    Install the Python bindings via pip from the bindings/python subdirectory.
    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
2026-05-27 fix api.py: set self.port before early-return when Flask is absent
    [api.py]
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2026-05-28 fix: GPIO_SLOWDOWN=1 for Pi 5 (RP1 chip needs 1, not 4)
    [config.py]
2026-06-01 fix: confirmed working panel config for Pi 4B + P3 FM6124 64x64
    [config.py]
2026-06-04 Fix photo timestamp precision to prevent file overwrites
    Changed timestamp format from YYYYMMDD_HHMMSS to YYYYMMDD_HHMMSS_ffffff
    (adding microseconds). This prevents filename collisions when two photos
    are saved within the same second, which could cause previous receipts
    or booth strips to be silently overwritten.
    Example: Two booth cycles finishing at 20:15:30.123 and 20:15:30.456
    would previously create the same filename and cause data loss.
    [photo_store.py]
2026-06-05 Fix: initialize self.mirror in MirrorAPI.__init__ before Flask check
    Moves self.mirror assignment to the start of __init__ to ensure it's
    always initialized, preventing potential AttributeError when Flask is
    unavailable.
    [api.py]
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2026-10-07 Bring up the HUB75 panel wall on Pi 4 + add panel_setup tooling
    Hardware-verified on Pi 4B "Fortuna" with 9x P3 64x64 FM6124 panels
    (3x3, 4th row to come) on an Adafruit HAT:
    - config: up to 12 panels in a 3-wide layout; measured settings
    (mapping "regular", panel_type FM6126A, pwm_bits 7, gpio_slowdown 6
    = ~67 Hz and clean on the long chain), physical chain order (row
    serpentine from bottom-left, middle row rotated 180), power budget.
    - led_matrix: flat-chain + software remap instead of pixel mappers,
    per-panel rotation, frame power limiter (40 A PSU), skip unchanged
    frames, optional per-panel colour gains via LUT.
    - main: --no-touch, --mock-camera, --auto/--auto-booth-every; idl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
    [camera.py, config.py, display_test.py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]
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2026-10-07 Add the Wheel of Fortuna: AI-written fates, spun on the wall, printed verdict
    - display/wheel_of_fortuna.py: OpenAI writes 8 cheeky outcomes for Fionn
    and Dewa at Fortunagasse (label, emoji, official verdict; built-in
    fallback set if the API fails). The Pi picks the winner at random. Spin
    animation with emoji on each slice, a ticker of the slice under the
    pointer, deceleration onto the winner, confetti, verdict screen, and a
    printed verdict card ("This ruling is final. No appeals.").
    - panel_setup/wheel.py: `--spins N`, `--no-print`, `--preview out.png`.
    [wheel.py]
2026-10-07 Add a slow generative art gallery for the wall
    display/art.py: five slow pieces, ~60 s each, with 4 s cross-fades -
    Ink Flow (particles on a divergence-free curl flow, soft tone-mapped
    trails), Colour Field (breathing Rothko-like blocks), Lava (metaballs),
    Coral (Gray-Scott reaction-diffusion, coral regime) and Interference
    (orbiting ring systems / moire). 4-14 ms per frame on the Pi.
    `play.py art`.
    [play.py]
2026-10-07 Lava & Coral gallery + start it automatically at boot
    - display/art.py: LavaPlus (classic lava lamp in purple glass, neon
    topography contours, mercury chrome, bioluminescence) and CoralPlus
    (Gray-Scott variants: 3D-lit brain coral, bloom from a single seed,
    pink mitosis, gold labyrinth; sim clamped to [0,1] so it can't blow
    up). LavaCoralGallery cycles 10 pieces, `play.py lava`.
    - panel_setup/install_autostart.sh: systemd wall-art.service runs a
    play.py animation at boot and restarts it if it dies; disables
    magic-mirror.service so only one program drives the panels.
    Verified across a reboot on the Pi.
    [play.py]
2026-10-07 Add live tram departures board (Zürich Rennweg, split-flap style)
    display/departures.py: fetches transport.opendata.ch every 30 s in the
    background (no API key), shows the next 7 trams with VBZ line-colour
    badges, shortened destinations and live minutes (scheduled + delay;
    delayed trams in orange, "now" pulses). Rows flip through random
    characters when they change, like a split-flap board. Header with
    station and clock; red dot if the data can't be fetched. `play.py trams`.
    [play.py]
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2026-10-07 Wall control website: pick shows, mirror mode, wheel, playlists, brightness
    panel_setup/wall_control.py (Flask, port 80, boot service via
    install_control.sh) is now the one program that drives the panels: each
    mode runs as a child process (play.py <anim>, main.py for mirror mode,
    wheel.py for a one-shot spin that returns to the current show), crashed
    modes restart (gives up after 5 in 2 min), playlists rotate every N
    minutes, and the choice + brightness persist in wall_state.json.
    panel_setup/web/index.html: phone-friendly page with preview thumbnails of
    every animation, now-playing card, brightness slider, Wheel of Fortuna
    (print on/off), mirror mode (laptop stream / demo / Pi camera, hand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
    [config.py, play.py, wall_control.py]
2026-10-07 Music mode: chill music-reactive art with an AI VJ
    display/music.py: listens to a UDP audio stream (Mac mic via
    panel_setup/stream_mic.sh) or ALSA (WALL_AUDIO=alsa:plughw:1 for a USB
    sound card later); per-band auto-gain, heavily smoothed bass/mid/treble,
    gentle beat detection. Five calm styles - lava swelling with the bass,
    coral that grows with energy and sprouts on beats, ink flow, aurora
    curtains, ripples on beats - in soft palettes, cross-faded. Every 40 s an
    AI VJ (gpt-audio) hears 8 s of audio and picks style + palette + a short
    caption, told the hallway is chill; feature-based fallback otherwise.
    Silence drifts into slow dusk lava. Added to play.py and the website.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
    [play.py, wall_control.py]
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2026-10-07 Music mode at 100% brightness, smooth, no music-driven flicker
    - wall_control: per-mode brightness (music defaults to 100%); the slider
    adjusts the current mode's own level when it has one
    - music: drift speed follows the music only over ~3 s; visuals see a
    ~1 s average of the bass; brightness no longer follows the music at
    all (glow orbs only breathe slightly in size, coral/aurora/ink keep a
    constant intensity) - on a light wall any luminance pulsing reads as
    flicker
    [wall_control.py]
2026-10-07 Revert "Music mode at 100% brightness, smooth, no music-driven flicker"
    This reverts commit 37feedc (back to the 2bc7fb7 behaviour, as requested).
    [wall_control.py]
2026-10-07 Music art from the app, AI designs the whole look; panel 0 timing; no text
    - music: live settings from the website (art style, colours, vibe; each
    can be Auto (AI) or fixed). App changes apply within ~2 s with a 4 s
    fade; AI changes keep the 3 min hold and 15 s fade. In Auto the AI also
    sets vibe, drift speed, shape size and number of shapes (soft limits),
    blended in over ~15 s with shapes fading rather than popping. The
    engine publishes what the AI hears for the app (never on the wall).
    Caption overlay removed. Dropped the retired gpt-4o-audio-preview.
    - wall_control: GET/POST /api/music; website Music card.
    - config: gpio_slowdown 7 (fewer data errors on the first panel), refre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
    [config.py, wall_control.py]
2026-10-07 AI light designer for music mode; vsync-locked frames; smoother motion
    - music: every 30 s the AI hears 10 s of audio plus context (time of day,
    measured energy/tempo, its last scenes) and designs a whole named scene:
    base style, optional screen-blended second layer + opacity, a preset or
    its own 4-colour palette (kept soft: deep shadow .. soft highlight),
    vibe, speed, size, shape count, softness. Everything is validated and
    clamped; scenes keep the 3 min hold and 15 s fades; design numbers
    blend over ~15 s. The app shows the scene name and colour swatches.
    - smoother: drift speed follows the music over ~3 s (no surge on each
    bass note); visuals breathe with a ~0.6 s bass avera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
    [led_matrix.py, play.py]
2026-10-07 Music: Mac/Pi microphone toggle, sensitivity slider, AI song recognition
    - source toggle (Mac stream via UDP, or the first ALSA capture device on
    the Pi - a USB sound card / mic); switching restarts listening; clear
    status/error in the app ("no microphone found on the Pi ...")
    - sensitivity slider 0-100 (0.3x .. 1x .. 2x reactions, silence floor
    follows), applied live
    - the AI names the song + artist only when it genuinely recognises it,
    and lets the song inspire the scene; shown in the app, never on the wall
    [wall_control.py]
2026-10-07 Music: designer brain switch (OpenAI or Claude CLI); retire the glow style
    - brain setting + app switch: "OpenAI - hears" (gpt-audio, listens to the
    clip) or "Claude - text" (Claude Code CLI, Haiku, every 60 s, designs
    from the Shazam song, bass/mid/treble, energy, tempo, time and its last
    scenes; cannot hear audio). Credentials via CLAUDE_CODE_OAUTH_TOKEN or
    ANTHROPIC_API_KEY in .env; missing CLI / token / errors are shown in
    the app and the wall falls back to the built-in rules. Tested with a
    stub CLI (parsing, clamping, every failure message); nothing installed
    or logged in on the Pi. Setup steps in panel_setup/README.md.
    - "glow" removed from the style list, layers, default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
    [wall_control.py]
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2026-10-08 Smart Life (Tuya) lights from the web app, local control
    lights.py: devices from the tinytuya wizard's devices.json (or
    panel_setup/lights.json), parallel on/off/status with timeouts so a dead
    or slow light never blocks the others, and a nightly "lights off at HH:MM"
    that fires once a day (and not hours late after a reboot). wall_control:
    /api/lights, /all, /one, /schedule + a watcher thread; app: Lights card
    (per-light switches, All off / All on, nightly time). tinytuya is installed
    by bootstrap_pi.sh; Tuya cloud secrets are excluded from deploy.sh and
    git. Tested against a fake tinytuya; needs the one-time Tuya setup at home
    (README).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
    [lights.py, wall_control.py]
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2026-10-08 App: "Mirror voice & people" card - tone slider, language, smile/recognise/learn switches, enrol, name and forget faces
    - /api/mirror/settings (tone 0-100, language, smile, recognise, learn_faces)
    - /api/faces list/enrol (looks through the mirror's camera for ~5 s)/forget/
    name suggestion/dismiss; enrol needs mirror mode
    - fix: "delete all face data" now reports how many records it removed
    [api.py, faces.py, wall_control.py]
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2026-10-08 Pixel selfie: face-centred 48x48 sprite in 10 colours, revealed row by row, sticker printed
    New trigger /api/trigger/pixel (app button "Pixel selfie"): countdown, photo,
    tight square around the face, bilateral smoothing, median-cut palette, 4x
    nearest-neighbour onto the wall, receipt printed with the sprite.
    [api.py, main.py, wall_control.py]
2026-10-08 Idle art: motion no longer brings the silhouette back unless 'wake on motion' is ticked in the app
    [main.py, mirror_settings.py]
2026-10-08 Wall start-up: loading bar, then the welcome animation once; lighter website; frame-timing stats
    - play.py: boot screen (HOUSE FORTUNA + progress bar) while the animation warms up;
    after a real power-on (WALL_BOOT set by wall_control for the first start only)
    the welcome animation plays once; numpy limited to 1 thread; WALL_STATS=1
    prints render/draw timing every 10 s
    - wall_control: runs at nice 12, only draws thumbnails when they are missing
    - deploy.sh ships the pre-made thumbnails (and skips gifs/)
    Claude-Session: https://claude.ai/code/session_0138cQdxWm6v4Mo29quZwNNu
    [play.py, wall_control.py]
2026-10-08 Artsy gallery (marbling, oil slick, watercolour, Kandinsky, op-art, Mondrian); remove lava lamp + mercury; fix stats crash
    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
    [play.py, wall_control.py]
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2026-10-08 VJ overhaul: beat tracker, 31 styles, effects, prompt box, faster reactions; lights/mic/wheel UI removed
    - display/beat.py: tempo (autocorrelation) + phase-locked beat clock; onset weighted to
    kick/bass; art pulses exactly on the beat (beat strength + sync offset in the app)
    - display/vj_fx.py: 19 more styles from Shapes/Artsy/Light Art, symmetry (mirror/quad/diag),
    hue drift, light trails, beat shockwave rings, drop detector, background pre-warm
    - AI designer: bolder prompt with the whole menu + music-matching guidance; new knobs (symmetry,
    trails, hue_drift, accent, reactivity, hold, fade), wider ranges, native palette; "tell the VJ"
    prompt box replaces the style/colour/vibe dropdo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
    [play.py, wall_control.py]
2026-10-08 VJ: two modes (Chill organic / Techno cool), organic modulation, tempo sets flow speed
    - Chill: soft painterly pool, long fades, no beat clock, no rings/symmetry; Techno: geometric neon pool,
    neon/violet/acid/ice palettes, symmetry, light beat influence, drops, shorter scenes
    - the AI is clamped to the mode's styles/palettes/ranges; mode switch changes the scene at once
    - visuals follow smoothed bass/mid/treble (organic), measured BPM scales the flow speed
    - removed beat sync/strength sliders; song text a bit more visible
    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
    [wall_control.py]
2026-10-08 VJ engine: continuous "party level" drives everything; slow house art; simpler app; Gemini retired
    - display/intensity.py: party level 0..1 from loudness (dBFS, the gate), beat lock, tempo, hits/s,
    bass share, with hysteresis (10 s up / 45 s down, slow drift in silence)
    - profile(): every range interpolates chill -> techno along the level; style pool chill / both /
    techno; symmetry and rings only at a real party (> 70 %), never on chill music
    - beat: downbeat + bar/phrase position; strong/weak pulse per beat; scene changes land on 4-bar
    boundaries at a party; build-up riser + drop surge only when it is a party
    - tracker resamples onsets onto a uniform grid (robust to render jitter); qu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
    [play.py, wall_control.py]
2026-10-08 VJ: no per-beat pulsing at all, party level is a slider (0 = art just breathes), listening is optional
    - the picture never pulses on the beat: pieces get a slow smoothed envelope, brightness breathes a
    few percent over seconds with the overall energy; rings/shockwaves removed; drops only quicken
    the flow briefly; crossfades >= 6 s; flow speed capped (never frantic)
    - party level: app slider 0-100 (default 15) replaces Auto/Chill/Party; "let the wall listen" is an
    optional switch under More (the room estimate is shown for reference)
    - big slider jumps pick a new scene from the new pool at once; small ones glide
    Claude-Session: ht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
    [play.py, wall_control.py]
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2026-10-08 Art cull + colour discipline + sleep-slow art; VJ loops player (Beeple CC packs, tempo-matched)
    - galleries keep only the strong pieces (Shapes 9, Light Art 6, Artsy 4); rainbow palettes
    replaced by one/two-hue ramps; VJ menu trimmed the same way
    - AI palettes are pulled to at most two neighbouring hues (_restrain); the brief says so
    - art pace default 12 % (slider 3-100 %); VJ chill end near-still
    - display/loops.py + tools/make_loops.py: 192x192 clips with motion/brightness index; a loop
    spans a whole number of beats when the tempo is locked; 'loops' is a VJ style
    Claude-Session: https://claude.ai/code/session_0138cQdxWm6v4Mo29q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
    [play.py, wall_control.py]
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2026-10-08 Organic pieces that breathe with the bass (jellyfish, living cells, breath rings), a waveform style, subtle bass coupling for line art, smoothed power limiter
    - display/organic.py: half-res pieces (2-8 ms) that swell with the smoothed bass; also in the Lava & Coral gallery
    - "wave": the actual audio waveform as a glowing line with a soft echo (VJ only)
    - line pieces (op-art, flow lines, truchet, harmonograph, poles, spiral) get heavier lines with the bass; flow
    speed nudges with it - gentle at the chill end
    - led_matrix: the current limiter's scale drops fast but recovers slowly (~2 s), so bright content near the
    budget no longer flickers at high brightness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
    [led_matrix.py]
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2026-10-09 Hardware: updated LED wall frame suite (parametric OpenSCAD sources, 3MF plates, STLs, renders, MakerWorld listing)
    Replaces the old frame folder; adds the compact Pi holder, C270 webcam box and touch box.
    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
    [00_fit_test_PRINT_FIRST.3mf, 00_fit_test_PRINT_FIRST.stl, 00b_dovetail_gauge_c005_c010_c015.3mf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]
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2026-10-09 Pages is the control app; credits to Dewa and Fionn; pieces evolve over hours
    - Pages home = the wall's control app; the gallery feed moves to /art/. The app finds the wall
    through a Cloudflare quick tunnel whose address the Pi announces in wall/wall.json, and logs in
    with a token (browser-saveable password form). On the home network nothing changes.
    - wall_control: token auth (cookie, bearer or ?k=), CORS for the Pages origin, lockout after 8 wrong
    passwords in 10 minutes, guest page home-network only, tunnel watcher (needs cloudflared)
    - credits: "Made by Dewa and Fionn" everywhere public; no Claude credit on the site
    - iClock uniform (hours since midnight); the daily brief asks for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
    [wall_control.py]
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
